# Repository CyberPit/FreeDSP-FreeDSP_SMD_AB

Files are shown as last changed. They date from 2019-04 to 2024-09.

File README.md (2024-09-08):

# FreeDSP-FreeDSP_SMD_AB

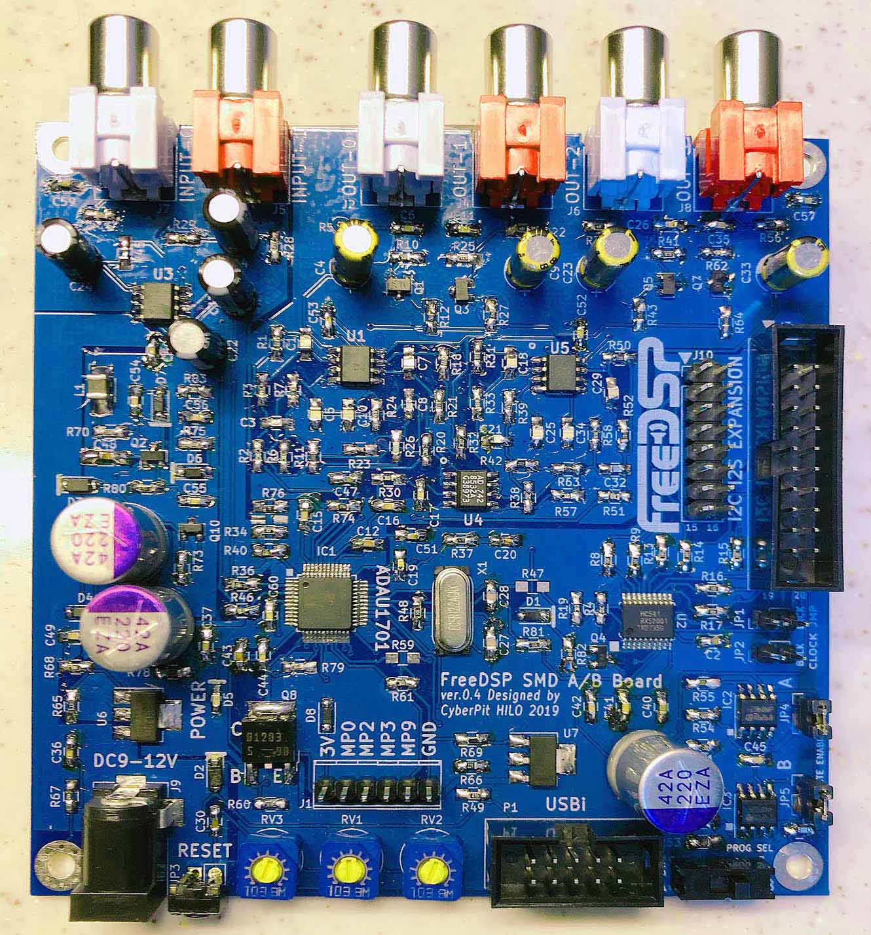
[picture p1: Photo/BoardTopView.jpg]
Image of FreeDSP Classic SMD A/B


- 2in4out RCA jacks
- A/B Selectable Boot EEPROMs
- ADAU1701 Single Board solution
- 0805(2.0mm x 1.25mm) SMD Resistors
- Through-hole Ele-Caps for better Audio performance
- 2V RMS Unity Gain Analog Audio I/O
- Absolute Phase Transparent.
- Power ON/OFF Audio Pops-Muting
- Buffered I2S I/O Headers (with Output Enable control feature)
- Onboard three semi-potentiometers or external controls via header pin. 

Project web page: (Direct Link)
https://cyberpithilo.web.fc2.com/audio/freedsp/index.html

Project web page: (Yandex Machine Translation)
https://translate.yandex.com/translate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

Project web page: (Google Machine Translation)
https://translate.google.com/translate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

I registered this design at SeedStudio(FusionPCB) project Gallary, so you can order this board here easily https://www.seeedstudio.com/FreeDSP-SMD-A-B-ADAU1701-1401-Audio-DSP-Processing-Boar-g-1230721

# License
This work and all other materials under https://github.com/freeDSP are licensed under a Creative Commons Attribution Share-Alike 4.0 license. This allows for both personal and commercial derivative works, as long as they credit freeDSP and release their designs under the same license.

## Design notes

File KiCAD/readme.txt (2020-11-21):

This PCB design was inherit from FreeDSP SMD.
Canages and improved in many points.
- Unity Gain I/O
- Selectable boot EEPROM
- Power ON/OFF Mute
- Buffered I2S I/O Headers

Errata: R49 47k ohms --> 4.7k ohms (Need to pull-up strong)

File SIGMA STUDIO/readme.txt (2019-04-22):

This folder contains example code for my FreeDSP_SMD_AB board.
All design required to output LRCK form MP10 port to drive Charge-Pump Circuity.
You need to set as Serial Output "MASTER MODE" and MP10 "In LRCK_out" in "Hardware Configuration">>"IC1-170x¥140x Register Control" tab.

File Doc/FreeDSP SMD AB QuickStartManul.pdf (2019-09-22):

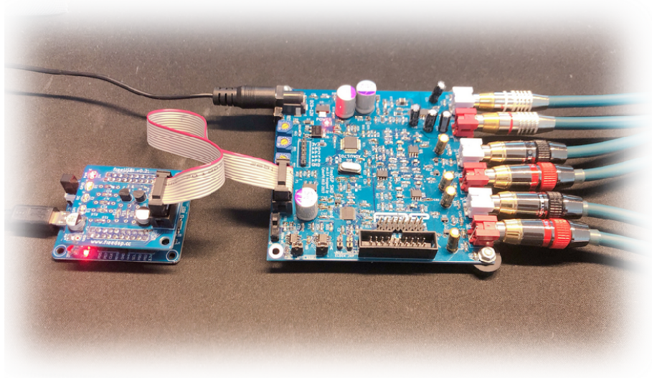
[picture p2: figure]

page of total 3
Quick Start Manual

# FreeDSP Classic SMD A/B

# Quick Start Manual

Version 1.0

## CyberPit HILO

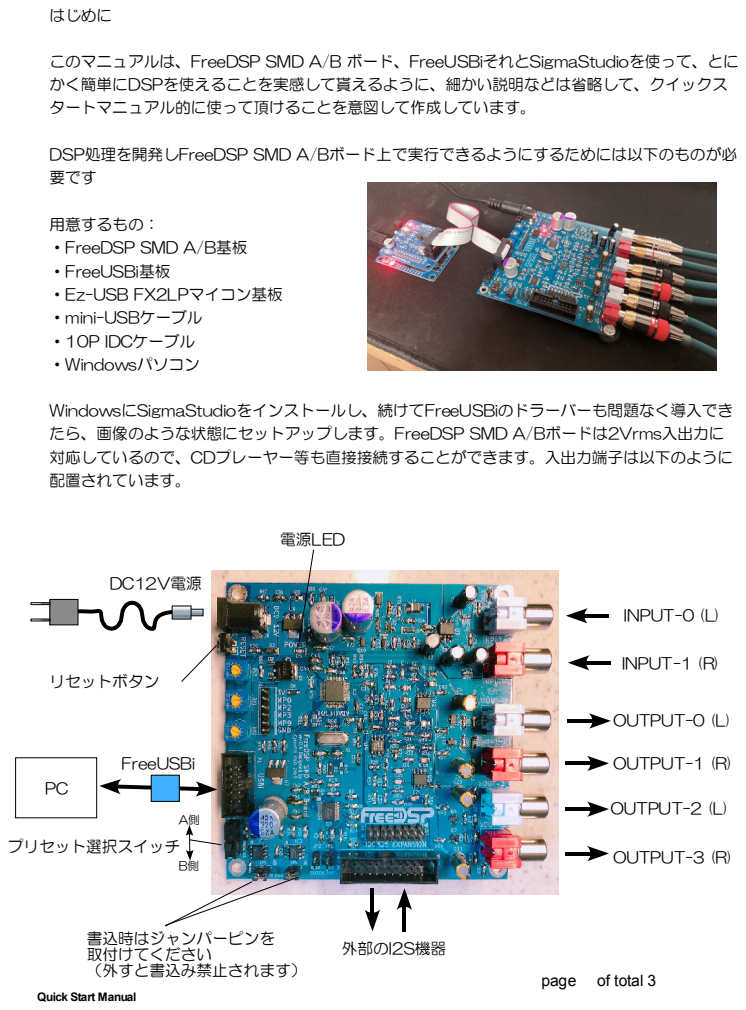
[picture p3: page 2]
はじめに; DC12V電源; INPUT-0 (L); INPUT-1 (R); OUTPUT-0 (L); OUTPUT-1 (R); OUTPUT-2 (L); OUTPUT-3 (R); 外部のI2S機器 書込時はジャンパーピンを 取付けてください （外すと書込み禁止されます）; FreeUSBi; プリセット選択スイッチ; リセットボタン; 電源LED

このマニュアルは、FreeDSP SMD A/B ボード、FreeUSBiそれとSigmaStudioを使って、とに
かく簡単にDSPを使えることを実感して貰えるように、細かい説明などは省略して、クイックス
タートマニュアル的に使って頂けることを意図して作成しています。

DSP処理を開発しFreeDSP SMD A/Bボード上で実行できるようにするためには以下のものが必
要です

用意するもの：
・FreeDSP SMD A/B基板
・FreeUSBi基板
・Ez-USB FX2LPマイコン基板
・mini-USBケーブル
・10P IDCケーブル
・Windowsパソコン

WindowsにSigmaStudioをインストールし、続けてFreeUSBiのドラーバーも問題なく導入でき
たら、画像のような状態にセットアップします。FreeDSP SMD A/Bボードは2Vrms入出力に
対応しているので、CDプレーヤー等も直接接続することができます。入出力端子は以下のように
配置されています。

SigmaStudioの操作：

1. 機材がセットできたらWindowsーPCでSigmaStudioを立ち上げます スタート >> AnalogDevices >> SigmaStudio4.2 >> SigmaStudio4.2
2. SigmaStudioが起動したらプロジェクトファイルを読み込みます
File >> Open 「2wayStereoChanDivDelayVolume .dspproj」を開く
3. 読み込めたら「Hardware Configuration」タブを選んでFreeUSBiが動作している事を確認 しましょう。（USB Interfaceモジュールの一番上の「USB」の文字背景色が緑色）
4. Link >> Compile >> Download ボタンを押してプログラムをDSPに転送します。
5. ２wayのチャンデバとして動作するのでInput0/1にオーディオ信号等を入力して、帯域分割さ れた出力がOut-0/1（低域）、Out-2/3(高域）が出力されるのでアンプとフルレンジSP等を接 続して動作を確認します。今はRV3のポテンショメータが無いので「SW vol」モジュールのゲイ ンが上げられず音がでないので削除しバイパスしてしまいます。
6. 「Schematic」タブを選んでから、「ADCin1」モジュールを削除、「SW vol」モジュールも 削除します。配線が無くなってしまうので緑色の接続点をクリックし接続先までバイパスする配 線を行います。
７. バイパス配線ができたら、Link >> Compile >> Download ボタンを押してプログラムを DSPに転送します。
８. EQモジュールの青いボタンを押してクロス周波数やスロープのパラメーターを変えると音が 変化することを確認してみてください。
9. 左側の「Tree Tool Box」からFileters >> Miscellaneous >> State Variableを選んで配置信 号経路に割り込むように配線してみて下さい。
10. Link >> Compile >> Download ボタンを押してプログラムをDSPに転送します。
11. 周波数やQを可変してみてください
12. 気に入ったセッテイングができたら File >> Save As... で名前を付けてPCに保存します。
13. ボード上のSW1を操作してプログラムを保存する側を選びます
14. 「Hardware Configuration」タブを選んで「ADAU1701」モジュールのIC1を右クリッ クし「Write Latest Compilation to E2ROM」を実行しファームをボードに書き込みます。 15 これで電源を入れればいつでもすぐに使える状態となりました。

サンプルプロジェクトのURL
https://cyberpithilo.web.fc2.com/audio/freedsp/2wayStereoChanDivDelayVolume.zip

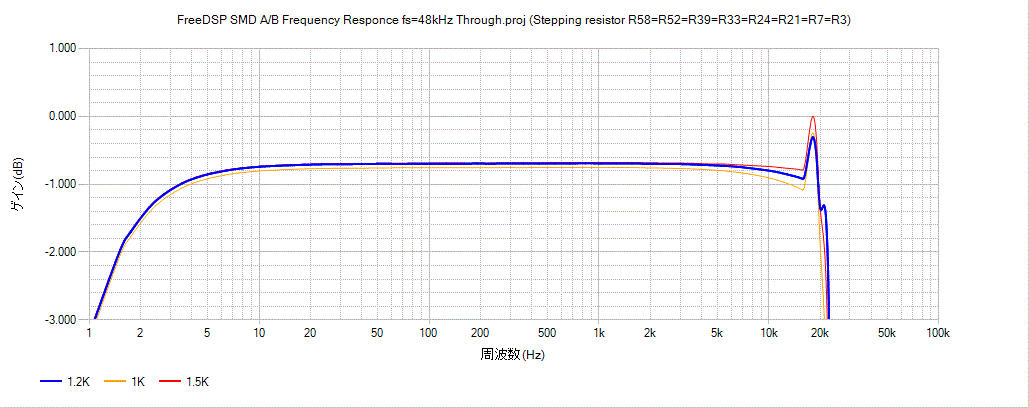
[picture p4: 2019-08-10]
Photo/resp_LPF-R_Stepping48k.gif

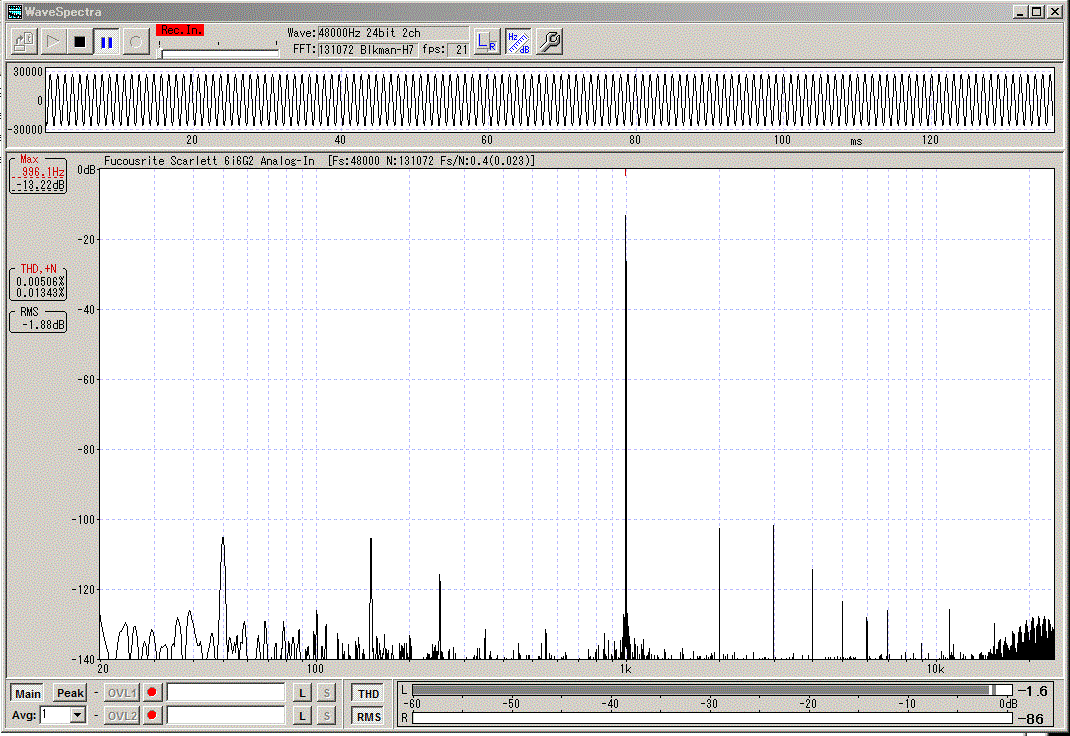
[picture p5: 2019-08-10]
Photo/THD-R.GIF

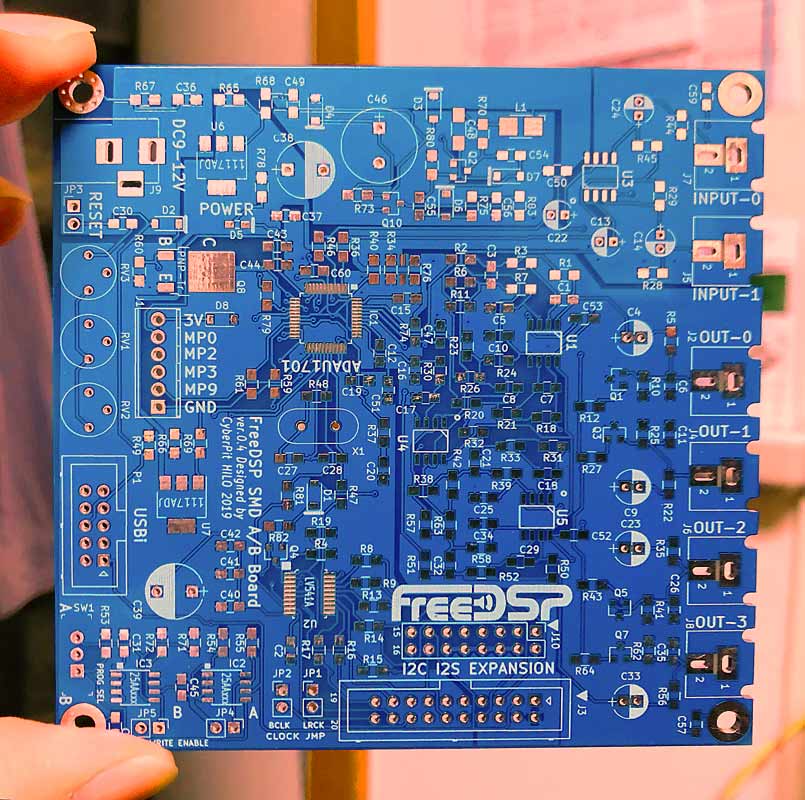
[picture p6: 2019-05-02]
Photo/Rev2BoardArrived.jpg

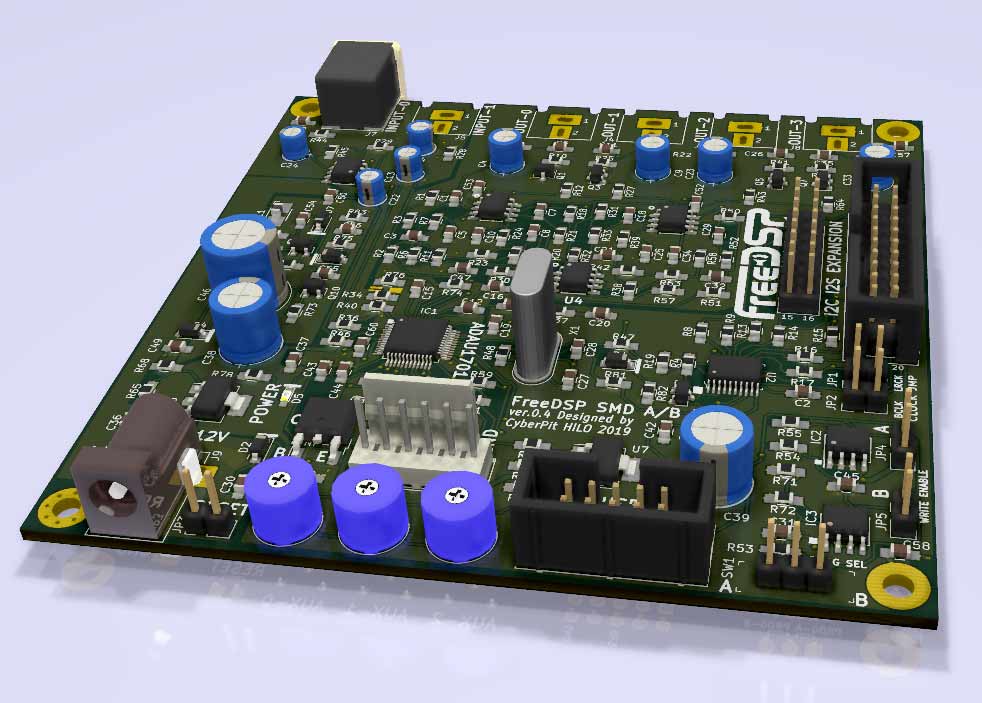
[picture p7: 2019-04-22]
Photo/3Dview_0v4.jpg

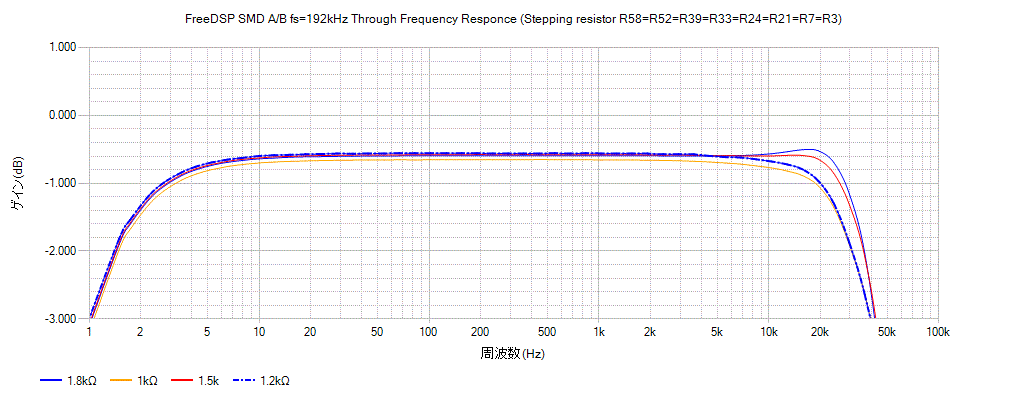
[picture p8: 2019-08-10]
Photo/resp_LPF-R_Stepping192k.GIF

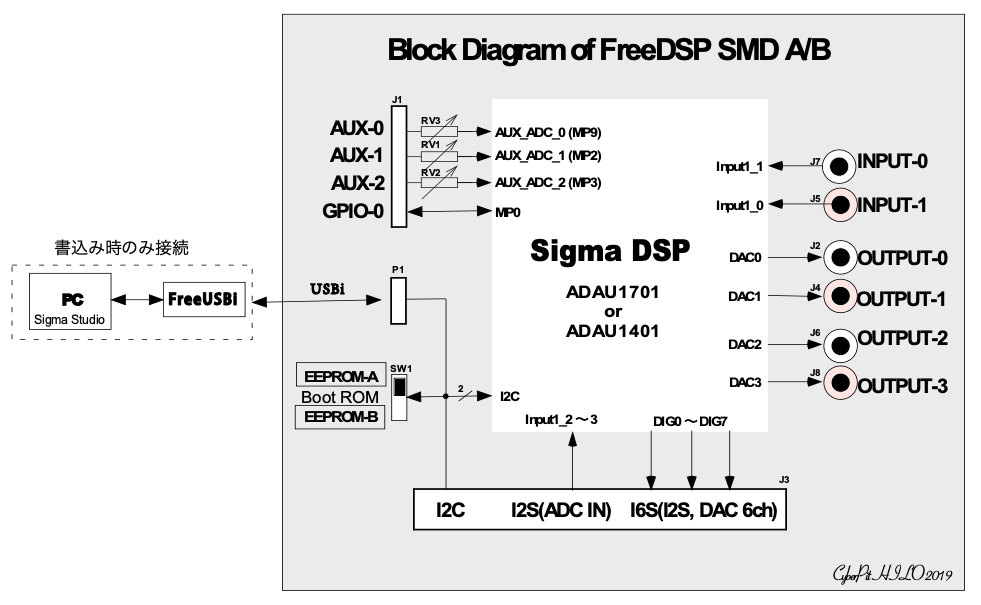
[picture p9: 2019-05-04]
SIGMA STUDIO/BlockDiagram.gif

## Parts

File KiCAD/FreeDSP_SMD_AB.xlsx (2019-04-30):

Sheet: FreeDSP_SMD_AB.csv
Source: |  |  | FreeDSP_SMD_AB.sch
Bill of materials for FreeDSP SDM A/B Board ver 0.4
Date: |  |  | Saturday, 1 Mayl 2019 at 11:13:14
Tool: |  |  | Eeschema (5.1.0-0)
Generator: |  |  | bom_csv_grouped_by_value_with_fp.py |  |  |  |  |  |  | ¥5392
Component Count: |  |  | 194
Ref | Type | OP | Std. Ver. | Optinal Ver. | Footprint | Value | Shop Link1 | Shop Link2 | 参考価格 | 小計
IC1, | U |  | 1 | 1 | QFP:LQFP-48_7x7mm_Pitch0.5mm | Analog Devices DSP ADAU1701 or ADAU1401 | https://jp.rs-online.com/web/p/audio-processors/7592705/ | https://www.digikey.com/product-detail/en/analog-devices-inc/ADAU1701JSTZ/ADAU1701JSTZ-ND/1246074 | ¥1124 | ¥1124
U2, | U | O | 0 | 1 | TSSOP-20_W4.4mm | 8bit 3-state Buffer 74LV541A | http://akizukidenshi.com/catalog/g/gI-03440/ | https://www.digikey.com/product-detail/en/texas-instruments/SN74LV541APWR/296-13700-1-ND/509734 | ¥200 | ¥200
U6, U7, | U |  | 2 | 2 | SOT_Packages_SMD:SOT-223-3_TabPin2 | Variable Voltage Regurator AZ1117-ADJ | http://akizukidenshi.com/catalog/g/gI-11194/ | https://www.digikey.com/product-detail/en/diodes-incorporated/AZ1117EH-ADJTRG1/AZ1117EH-ADJTRG1DICT-ND/5001334 | ¥30 | ¥60
U5, U3, U1, U4, | U |  | 4 | 4 | SOIC127P600X175-8N | Dual Op-Amp LME49720MA or Equiv. | http://akizukidenshi.com/catalog/g/gI-08175/ | https://www.digikey.com/product-detail/en/texas-instruments/LME49720MAX-NOPB/LME49720MAX-NOPBCT-ND/3527060 | ¥180 | ¥720
IC2, IC3, | U |  | 2 | 2 | SOIC-8_3.9x4.9mm_Pitch1.27mm | I2C EEPROM 24AA256 (or Bigger) | http://akizukidenshi.com/catalog/g/gI-10492/ | https://www.digikey.com/product-detail/en/microchip-technology/25AA256-I-SN/25AA256-I-SN-ND/665597 | ¥40 | ¥80
Q1, Q3, Q5, Q7, | Q |  | 4 | 4 | TO_SOT_Packages_SMD:SOT-23 | 2SD2704KT146 or 2SC3326 | http://akizukidenshi.com/catalog/g/gI-06007/ | https://www.digikey.com/product-detail/en/rohm-semiconductor/2SD2704KT146/2SD2704KT146CT-ND/1782342 | ¥5 | ¥20
Q8, | Q |  | 1 | 1 | TO_SOT_Packages_SMD:TO-252-2 | 2SB1203 (PNP transistor, base/collector/emitter) | http://akizukidenshi.com/catalog/g/gI-06602/ | https://www.digikey.com/product-detail/en/on-semiconductor/2SB1203S-TL-E/2SB1203S-TL-EOSCT-ND/5801673 | ¥10 | ¥10
Q2, Q4, | Q |  | 1 | 2 | TO_SOT_Packages_SMD:SOT-23 | 2N7002 (0.115A Id, 60V Vds, N-Channel MOSFET) | http://akizukidenshi.com/catalog/g/gI-04256/ | https://www.digikey.com/product-detail/en/nexperia-usa-inc/2N7002P215/1727-4692-1-ND/2531105 | ¥20 | ¥40
Q10, | Q |  | 1 | 1 | TO_SOT_Packages_SMD:SOT-23 | IRLML6402 (-3.7A Id, -20V Vds, P-Channel MOSFET, 65mOhm Rd) | http://akizukidenshi.com/catalog/g/gI-02553/ | https://www.digikey.com/product-detail/en/infineon-technologies/IRLML6402TRPBF/IRLML6402PBFCT-ND/812500 | ¥20 | ¥20
D3, D2, | D |  | 2 | 2 | Diodes_SMD:D_SOD-123 | Fast Switching Si Diode N4148W | http://akizukidenshi.com/catalog/g/gI-07084/ | https://www.digikey.com/product-detail/en/micro-commercial-co/1N4148WX-TP/1N4148WXTPMSCT-ND/717312 | ¥3 | ¥6
D6, D7, D8, D4, D1, | D |  | 2 | 4 | Diodes_SMD:D_SOD-123 | Schottky diode RB160M-30 | http://akizukidenshi.com/catalog/g/gI-01398/ | https://www.digikey.com/product-detail/en/nexperia-usa-inc/BAT54H115/1727-3569-1-ND/1127204 | ¥15 | ¥60
D5, | D |  | 1 | 1 | LEDs:LED_0603_HandSoldering | SMD LED (1.6mm x 0.8mm, RED) | http://akizukidenshi.com/catalog/g/gI-11879/ | https://www.digikey.com/product-detail/en/rohm-semiconductor/SML-D12U1WT86/SML-D12U1WT86CT-ND/5843858 | ¥10 | ¥10
L1, | L |  | 1 | 1 | Inductors:Inductor_1212 | SMD-INDUCTOR-33uH (700MA,_6mmX6.4mm) | http://akizukidenshi.com/catalog/g/gP-05691/ | https://www.digikey.com/product-detail/en/taiyo-yuden/CB2016T330K/587-2472-1-ND/2230338 | ¥5 | ¥5
R55, R72, R61, R6, R2, R23, R20, R38, R32, R57, R51, R30, R19, R4, R83, | R |  | 14 | 15 | Resistors_SMD:R_0805_HandSoldering | 10k |  |  |  | ¥0
R60, R7, R3, R24, R21, R39, R33, R58, R52, R75, R78, R70, R79, | R |  | 13 | 13 | Resistors_SMD:R_0805_HandSoldering | 1k |  |  |  | ¥0
R1, R18, R31, R50, R11, R26, R42, R63, R64, R43, R27, R12, | R |  | 12 | 12 | Resistors_SMD:R_0805_HandSoldering | 22k |  |  |  | ¥0
R49, R62, R41, R25, R10, R44, R28, | R |  | 7 | 7 | Resistors_SMD:R_0805_HandSoldering | 47k |  |  |  | ¥0
R56, R35, R22, R5, R68, | R |  | 5 | 5 | Resistors_SMD:R_0805_HandSoldering | 680R |  |  |  | ¥0
R45, R29, R67, R74, R82, | R |  | 4 | 5 | Resistors_SMD:R_0805_HandSoldering | 100k |  |  |  | ¥0
R34, R76, R80, | R |  | 3 | 3 | Resistors_SMD:R_0805_HandSoldering | 0R |  |  |  | ¥0
R54, R53, R71, | R |  | 3 | 3 | Resistors_SMD:R_0805_HandSoldering | 2k2 |  |  |  | ¥0
R36, R40, R46, | R |  | 3 | 3 | Resistors_SMD:R_0805_HandSoldering | 18k |  |  |  | ¥0
R66, R65, | R |  | 2 | 2 | Resistors_SMD:R_0805_HandSoldering | 220R |  |  |  | ¥0
R48, R8, R9, R13, R14, R15, R16, R17, R81, | R |  | 1 | 9 | Resistors_SMD:R_0805_HandSoldering | 100R |  |  |  | ¥0
R69, | R |  | 1 | 1 | Resistors_SMD:R_0805_HandSoldering | 360R |  |  |  | ¥0
R37, | R |  | 1 | 1 | Resistors_SMD:R_0805_HandSoldering | 470R |  |  |  | ¥0
R73, | R |  | 1 | 1 | Resistors_SMD:R_0805_HandSoldering | 1MEG |  |  |  | ¥0
C27, C28, | C |  | 2 | 2 | Capacitors_SMD:C_0805_HandSoldering | 22p | MLCC |  | ¥3 | 6
C20, | C |  | 1 | 1 | Capacitors_SMD:C_0805_HandSoldering | 0.056uF | MLCC |  |  | ¥0
C41, | C |  | 1 | 1 | Capacitors_SMD:C_0805_HandSoldering | 1u/6.3V | MLCC |  |  | ¥0
C44, C31, C45, C17, C2, C52, C53, C50, C51, C57, C58, C59, C60, C42, C37, | C |  | 12 | 13 | Capacitors_SMD:C_0805_HandSoldering | 0.1u | MLCC |  |  | 0
C5, C1, C10, C7, C25, C18, C34, C29, | C |  | 8 | 8 | Film Capacitors_SMD:C_0805_HandSoldering | 150P (Panasonic ECHU) | https://www.sengoku.co.jp/mod/sgk_cart/search.php?cid=3300 | https://www.digikey.com/product-detail/en/panasonic-electronic-components/ECH-U1C151JX5/PCF1461CT-ND/431695 | ¥34 | 272
C3, C8, C21, C32, | C |  | 4 | 4 | Film Capacitors_SMD:C_0805_HandSoldering | 1000PF (Panasonic ECHU) | https://www.sengoku.co.jp/mod/sgk_cart/search.php?cid=3300 | https://www.digikey.com/product-detail/en/panasonic-electronic-components/ECH-U1C102JX5/PCF1471CT-ND/431715 | ¥34 | 136
C19, C35, C26, C11, C6, | C |  | 5 | 5 | Capacitors_SMD:C_0805_HandSoldering | 3300pF | MLCC |  |  | 0
C43, C16, C12, C15, C40, | C |  | 7 | 7 | Capacitors_SMD:C_0805_HandSoldering | 10u/6.3V | MLCC |  |  | 0
C36, C48, | C |  | 7 | 7 | Capacitors_SMD:C_0805_HandSoldering | 10u/16V | MLCC |  |  | 0
C30, C47, C49 | C |  | 6 | 6 | Capacitors_SMD:C_0805_HandSoldering | 2.2u/6.3V | MLCC |  |  | 0
C54, C55, C56, | C |  | 6 | 6 | Capacitors_SMD:C_0805_HandSoldering | 2.2u/16V | MLCC |  |  | 0
C24, C14, | C |  | 2 | 2 | Capacitors_THT:CP_Radial_D4.0mm_P2.00mm | Polarized capacitor 2.2uF/16 | http://akizukidenshi.com/catalog/g/gP-03171/ |  | ¥10 | 20
C4, C9, C23, C33, | C |  | 4 | 4 | Capacitors_THT:CP_Radial_D5.0mm_P2.00mm | Polarized capacitor10u/16V | http://akizukidenshi.com/catalog/g/gP-04621/ |  | ¥10 | 40
C13, C22, | C |  | 2 | 2 | Capacitors_THT:CP_Radial_D4.0mm_P2.00mm | Polarized capacitor 47uF/6.3 | http://akizukidenshi.com/catalog/g/gP-05186/ |  | ¥20 | 40
C46, | C |  | 1 | 1 | Capacitors_THT:CP_Radial_Tantal_D10.5mm_P5.00mm | Polarized capacitor 220u/6.3V | http://akizukidenshi.com/catalog/g/gP-10272/ |  | ¥20 | 20
C38, C39, | C |  | 2 | 2 | Capacitors_THT:CP_Radial_D8.0mm_P5.00mm | Polarized capacitor 220u/16V | http://akizukidenshi.com/catalog/g/gP-10272/ |  | ¥20 | 40
SW1, | S |  | 1 | 1 | Switch_Slide_11.6x4mm_EG1218 | Slide SW_SPDT | http://akizukidenshi.com/catalog/g/gP-08790/ | https://www.digikey.com/product-detail/en/te-connectivity-alcoswitch-switches/1825282-1/450-1635-ND/1308844 | ¥20 | ¥20
X1, | X |  | 1 | 1 | Crystals:Crystal_HC49-U_Vertical | 12.288MHz Crystal | https://jp.rs-online.com/web/p/crystal-units/5476496/ | https://www.digikey.com/product-detail/en/txc-corporation/9B-12.288MEEJ-B/887-1239-ND/2207659 | ¥143 | ¥143
JP4, JP5, JP2, JP1, | H |  | 2 | 4 | Pin_Headers:Pin_Header_Straight_1x02_Pitch2.54mm | 2P Pin Header Conn_01x02 (P=2.54mm) | http://akizukidenshi.com/catalog/g/gC-08593/ | https://www.digikey.com/product-detail/en/harwin-inc/M20-9990246/952-2262-ND/3728226 | ¥3 | ¥12
JP3, | H |  | 1 | 1 | Pin_Headers:Pin_Header_Straight_1x02_Pitch2.54mm | SPST TACT Push Switch or 2P Pin Header | http://akizukidenshi.com/catalog/g/gP-08080/ | https://www.digikey.com/product-detail/en/omron-electronics-inc-emc-div/B3WN-6002/SW425CT-ND/277858 | ¥12 | ¥12
P1, | H |  | 1 | 1 | Connectors_Multicomp:Multicomp_MC9A12-1034_2x05x2.54mm_Straight | 10P MIL Male MIL Header Conn_02x05 (P=2.54mm) for USBi | http://akizukidenshi.com/catalog/g/gC-12664/ | https://www.digikey.com/product-detail/en/on-shore-technology-inc/302-S101/ED1543-ND/2178422 | ¥20 | ¥20
J5, J2, J6, | J |  | 6 | 6 | MyFootprints:RJ-2410N | Single RCA Conn_Coaxial (WHITE) | http://akizukidenshi.com/catalog/g/gC-02386/ | https://www.digikey.com/product-detail/en/switchcraft-inc/PJRAN1X1U02X/PJRAN1X1U02X-ND/1832412 | ¥40 | ¥240
J7, J4, J8, | J |  | 6 | 6 | MyFootprints:RJ-2410N | Single RCA Conn_Coaxial (RED) | http://akizukidenshi.com/catalog/g/gC-02385/ | https://www.digikey.com/product-detail/en/cui-inc/RCJ-042/CP-1419-ND/408506 | ¥40 | ¥240
J9, | J |  | 1 | 1 | Connect:BARREL_JACK | DC Power Jack (2.1mm Center, 5.5mm Sleeve) | http://akizukidenshi.com/catalog/g/gC-06568/ | https://www.digikey.com/product-detail/en/adafruit-industries-llc/3643/1528-2553-ND/8346574 | ¥40 | ¥40
RV3, RV2, RV1, | V | O | 0 | 3 | Potentiometers:Potentiometer_Trimmer_Bourns_3339P_Horizontal | POT_TRIM RESISTOR B10K | http://akizukidenshi.com/catalog/g/gP-06110/ | https://www.digikey.com/product-detail/en/bourns-inc/3339H-1-103LF/3339H-103LF-ND/1088280 | ¥50 | ¥150
J1, | H | O | 0 | 1 | TerminalBlock_Phoenix:TerminalBlock_Phoenix_MPT-2.54mm_6pol | 6P Pin Header 01x06 (P=2.54mm) | http://akizukidenshi.com/catalog/g/gC-01669/ | https://www.digikey.com/product-detail/en/te-connectivity-amp-connectors/640456-6/A1923-ND/109008 | ¥20 | ¥20
J10, | H | O | 0 | 1 | Pin_Headers:Pin_Header_Straight_2x08_Pitch2.54mm | 16P Pin Header Conn_02x08 (P=2.54mm) | http://akizukidenshi.com/catalog/g/gC-00082/ | https://www.digikey.com/product-detail/en/amphenol-icc-fci/68602-116HLF/609-3364-ND/1878523 | ¥50 | ¥50
J3, | H | O | 0 | 1 | Connectors_Multicomp:Multicomp_MC9A12-2034_2x10x2.54mm_Straight | 20P Pin Header 02x10 (P=2.54) | http://akizukidenshi.com/catalog/g/gC-05176/ | https://www.digikey.com/product-detail/en/on-shore-technology-inc/302-S201/ED10524-ND/2794235 | ¥20 | ¥20
 |  |  |  |  |  |  |  |  |  | ¥908
AC ADOUPTOR (DC12V 1A, 2.1mm Center +) | P |  | 1 | 1 | Power Supply (DC12V, 1A, 2.1mm Center Positive, 5.5mm Sleeve) |  | http://akizukidenshi.com/catalog/g/gM-11994/ |  | ¥580 | ¥580
Jumper Short-Pin (for Write Enables) | J |  | 2 | 2 | Jumper Short-Pin |  | http://akizukidenshi.com/catalog/g/gP-03687/ | https://www.digikey.com/product-detail/en/3m/D89110-0131HK-3365-10-D-6/3M156030-MC10G-3M156030-6-ND/6024552 | ¥4 | 8

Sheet: FreeUSBi_ThroughHole.csv
Reference | Qty. | Value | SMD/TH | Footprint | Shop URL
P1, P4 | 2 | CONN_02X10 | COM | Pin_Header_Socker Straight_2x10 | http://akizukidenshi.com/catalog/g/gC-00083/
P2 | 1 | CONN_02X05 | COM | IDC-Header_2x05_Pitch2.54mm_Straight | http://akizukidenshi.com/catalog/g/gC-12664/
D1 | 1 | LED | COM | LEDs:LED-3MM
D2 | 1 | LED | COM | LEDs:LED-3MM
D3 | 1 | LED | COM | LEDs:LED-3MM
D4 | 1 | LED | COM | LEDs:LED-3MM
C1、C2 | 2 | 100u | COM | Capacitors_Elko_ThroughHole:Elko_vert_11.2x6.3mm_RM2.5_CopperClear
P3 | 1 | CONN_01X02 | NOPOP | fdsp_pinheader:Pin_Header_Straight_1x02 | Directly Jumper wire conncetion to the Ez-USB FX2LP Board 5V
Q1, Q2 | 2 | 2N7000 | TH | TO_SOT_Packages_THT:TO-92_Inline_Narrow_Oval | http://akizukidenshi.com/catalog/g/gI-13045/
R1 | 1 | 51R | TH | Resistors_THT:R_Axial_DIN0204_L3.6mm_D1.6mm_P7.62mm_Horizontal | Free Size (1.6mm x 0.8mm, 2.0mm x 1.25mm, 3.2mm x 1.6mm)
R2, R5, R6, R7, R9 | 5 | 470R | TH | Resistors_THT:R_Axial_DIN0204_L3.6mm_D1.6mm_P7.62mm_Horizontal | Free Size (1.6mm x 0.8mm, 2.0mm x 1.25mm, 3.2mm x 1.6mm)
R8 | 1 | 1M | TH | Resistors_THT:R_Axial_DIN0204_L3.6mm_D1.6mm_P7.62mm_Horizontal | Free Size (1.6mm x 0.8mm, 2.0mm x 1.25mm, 3.2mm x 1.6mm)
R3, R4 | 2 | 10k | TH | Resistors_THT:R_Axial_DIN0204_L3.6mm_D1.6mm_P7.62mm_Horizontal | Free Size (1.6mm x 0.8mm, 2.0mm x 1.25mm, 3.2mm x 1.6mm)
10P IDC Cable Assy. | 1 | - | COM | Programming Cable | http://akizukidenshi.com/catalog/g/gC-03796/
Mini USB Cable | 1 | - | COM | USB-A to mini-USB | http://akizukidenshi.com/catalog/g/gC-07606/
Ez-USB FX2LP Board | 1 | - | COM | Various Choice | https://www.amazon.co.jp/SODIAL-%E9%96%8B%E7%99%BA%E3%83%9C%E3%83%BC%E3%83%89USB2-0-EZ-USB-FX2LP-CY7C68013A/dp/B00OCEEIX0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

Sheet: FreeUSBi_SMD.csv
Reference | Qty. | Value | SMD/TH | Footprint | Shop URL
P1, P4 | 2 | CONN_02X10 | COM | Pin_Header_Socker Straight_2x10 | http://akizukidenshi.com/catalog/g/gC-00083/
P2 | 1 | CONN_02X05 | COM | IDC-Header_2x05_Pitch2.54mm_Straight | http://akizukidenshi.com/catalog/g/gC-12664/
D1 | 1 | LED | COM | LEDs:LED-3MM
D2 | 1 | LED | COM | LEDs:LED-3MM
D3 | 1 | LED | COM | LEDs:LED-3MM
D4 | 1 | LED | COM | LEDs:LED-3MM
C1、C2 | 2 | 100u | COM | Capacitors_Elko_ThroughHole:Elko_vert_11.2x6.3mm_RM2.5_CopperClear | http://akizukidenshi.com/catalog/g/gP-05002/
P3 | 1 | CONN_01X02 | NOPOP | fdsp_pinheader:Pin_Header_Straight_1x02 | Directly Jumper wire conncetion to the Ez-USB FX2LP Board 5V
Q3, Q4 | 2 | 2N7002 | SMD | digikey-footprints:SOT-23-3 | http://akizukidenshi.com/catalog/g/gI-04256/
R10 | 1 | 51R | SMD | Resistors_SMD:R_0805_HandSoldering
R11, R13, R16, R17, R18 | 5 | 470R | SMD | Resistors_SMD:R_0805_HandSoldering
R14 | 1 | 1M | SMD | Resistors_SMD:R_0805_HandSoldering
R12, R15 | 2 | 10k | SMD | Resistors_SMD:R_0805_HandSoldering
10P IDC Cable Assy. | 1 | - | COM | Programming Cable | http://akizukidenshi.com/catalog/g/gC-03796/
Mini USB Cable | 1 | - | COM | USB-A to mini-USB | http://akizukidenshi.com/catalog/g/gC-07606/
Ez-USB FX2LP Board | 1 | - | COM | Various Choice | https://www.amazon.co.jp/SODIAL-%E9%96%8B%E7%99%BA%E3%83%9C%E3%83%BC%E3%83%89USB2-0-EZ-USB-FX2LP-CY7C68013A/dp/B00OCEEIX0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

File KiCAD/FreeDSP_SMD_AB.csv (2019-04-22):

Source: | FreeDSP_SMD_AB.sch
Date: | Saturday, 20 April 2019 at 11:13:14
Tool: | Eeschema (5.1.0-0)
Generator: | bom_csv_grouped_by_value_with_fp.py
Component Count: | 194
Ref | Std. Ver. | Optinal Ver. | Footprint | Value | Shop Link1 | Shop Link2 | 参考価格 | 小計
IC1, | 1 | 1 | Housings_QFP:LQFP-48_7x7mm_Pitch0.5mm | Analog Devices DSP ADAU1701 | https://jp.rs-online.com/web/p/audio-processors/7089748/ |  | 1243 | 1243
U5, U3, U1, U4, | 4 | 4 | LME49720MA_NOPB:SOIC127P600X175-8N | Dual Op-Amp LME49720MA or Equiv. | http://akizukidenshi.com/catalog/g/gI-08175/ |  | 180 | 720
U2, | 0 | 1 | digikey-footprints:TSSOP-20_W4.4mm | 8bit 3-state Buffer 74LV541A | http://akizukidenshi.com/catalog/g/gI-03440/ |  | 200 | 200
IC2, IC3, | 2 | 2 | Housings_SOIC:SOIC-8_3.9x4.9mm_Pitch1.27mm | I2C EEPROM 24AA256 (or Bigger) | http://akizukidenshi.com/catalog/g/gI-10492/ |  | 40 | 80
Q8, | 1 | 1 | TO_SOT_Packages_SMD:TO-252-2 | 2SB1203 (PNP transistor, base/collector/emitter) | http://akizukidenshi.com/catalog/g/gI-06602/ |  | 10 | 10
Q1, Q3, Q5, Q7, | 4 | 4 | TO_SOT_Packages_SMD:SOT-23 | 2SD2704KT146 or 2SC3326 | http://akizukidenshi.com/catalog/g/gI-06007/ |  | 5 | 20
Q2, Q4, | 1 | 2 | TO_SOT_Packages_SMD:SOT-23 | 2N7002 (0.115A Id, 60V Vds, N-Channel MOSFET) | http://akizukidenshi.com/catalog/g/gI-04256/ |  | 20 | 40
Q10, | 1 | 1 | TO_SOT_Packages_SMD:SOT-23 | IRLML6402 (-3.7A Id, -20V Vds, P-Channel MOSFET, 65mOhm Rd) | http://akizukidenshi.com/catalog/g/gI-02553/ |  | 20 | 20
U6, U7, | 2 | 2 | TO_SOT_Packages_SMD:SOT-223-3_TabPin2 | Variable Voltage Regurator AZ1117-ADJ | http://akizukidenshi.com/catalog/g/gI-11194/ |  | 30 | 60
D5, | 1 | 1 | LEDs:LED_0603_HandSoldering | SMD LED (1.6mm x 0.8mm, RED) | http://akizukidenshi.com/catalog/g/gI-11879/ |  | 10 | 10
D3, D2, | 2 | 2 | Diodes_SMD:D_SOD-123 | Fast Switching Si Diode N4148W | http://akizukidenshi.com/catalog/g/gI-07084/ |  | 3 | 6
D6, D7, D8, D4, D1, | 2 | 4 | Diodes_SMD:D_SOD-123 | Schottky diode RB160M-30 | http://akizukidenshi.com/catalog/g/gI-01398/ |  | 15 | 60
X1, | 1 | 1 | Crystals:Crystal_HC49-U_Vertical | 12.288MHz Crystal | https://jp.rs-online.com/web/p/crystal-units/5476496/ |  | 143 | 143
RV3, RV2, RV1, | 0 | 3 | Potentiometers:Potentiometer_Trimmer_Bourns_3339P_Horizontal | POT_TRIM RESISTOR B10K | http://akizukidenshi.com/catalog/g/gP-06110/ |  | 50 | 150
JP3, | 1 | 1 | Pin_Headers:Pin_Header_Straight_1x02_Pitch2.54mm | SPST TACT Push Switch or 2P Pin Header | http://akizukidenshi.com/catalog/g/gP-08080/ |  | 12 | 12
JP4, JP5, JP2, JP1, | 2 | 4 | Pin_Headers:Pin_Header_Straight_1x02_Pitch2.54mm | 2P Pin Header Conn_01x02 (P=2.54mm) | http://akizukidenshi.com/catalog/g/gC-08593/ |  | 3 | 12
J1, | 0 | 1 | TerminalBlock_Phoenix:TerminalBlock_Phoenix_MPT-2.54mm_6pol | 6P Pin Header 01x06 (P=2.54mm) | http://akizukidenshi.com/catalog/g/gC-01669/ |  | 20 | 20
J10, | 0 | 1 | Pin_Headers:Pin_Header_Straight_2x08_Pitch2.54mm | 16P Pin Header Conn_02x08 (P=2.54mm) | http://akizukidenshi.com/catalog/g/gC-00082/ |  | 50 | 50
J3, | 0 | 1 | Connectors_Multicomp:Multicomp_MC9A12-2034_2x10x2.54mm_Straight | 20P Pin Header 02x10 (P=2.54) | http://akizukidenshi.com/catalog/g/gC-05176/ |  | 20 | 20
P1, | 1 | 1 | Connectors_Multicomp:Multicomp_MC9A12-1034_2x05x2.54mm_Straight | 10P MIL Male MIL Header Conn_02x05 (P=2.54mm) for USBi | http://akizukidenshi.com/catalog/g/gC-12664/ |  | 20 | 20
J5, J2, J6, | 6 | 6 | MyFootprints:RJ-2410N | Single RCA Conn_Coaxial (WHITE) | http://akizukidenshi.com/catalog/g/gC-02386/ |  | 40 | 240
J7, J4, J8, | 6 | 6 | MyFootprints:RJ-2410N | Single RCA Conn_Coaxial (RED) | http://akizukidenshi.com/catalog/g/gC-02385/ |  | 40 | 240
J9, | 1 | 1 | Connect:BARREL_JACK | DC Power Jack (2.1mm Center, 5.5mm Sleeve) | http://akizukidenshi.com/catalog/g/gC-06568/ |  | 40 | 40
SW1, | 1 | 1 | digikey-footprints:Switch_Slide_11.6x4mm_EG1218 | Slide SW_SPDT | http://akizukidenshi.com/catalog/g/gP-08790/ |  | 20 | 20
L1, | 1 | 1 | Inductors:Inductor_1212 | SMD-INDUCTOR-10uH (225MA,_0806) | http://akizukidenshi.com/catalog/g/gP-06984/ |  | 5 | 5
C46, | 1 | 1 | Capacitors_THT:CP_Radial_Tantal_D10.5mm_P5.00mm | Polarized capacitor 220u/6.3V | http://akizukidenshi.com/catalog/g/gP-10272/ |  | 20 | 20
C38, C39, | 2 | 2 | Capacitors_THT:CP_Radial_D8.0mm_P5.00mm | Polarized capacitor 220u/16V | http://akizukidenshi.com/catalog/g/gP-10272/ |  | 20 | 40
C4, C9, C23, C33, | 4 | 4 | Capacitors_THT:CP_Radial_D5.0mm_P2.00mm | Polarized capacitor10u/16V | http://akizukidenshi.com/catalog/g/gP-04621/ |  | 10 | 40
C13, C22, | 2 | 2 | Capacitors_THT:CP_Radial_D4.0mm_P2.00mm | Polarized capacitor 47uF/6.3 | http://akizukidenshi.com/catalog/g/gP-05186/ |  | 20 | 40
C24, C14, | 2 | 2 | Capacitors_THT:CP_Radial_D4.0mm_P2.00mm | Polarized capacitor 2.2uF/16 | http://akizukidenshi.com/catalog/g/gP-03171/ |  | 10 | 20
C27, C28, | 2 | 2 | Capacitors_SMD:C_0805_HandSoldering | 22p |  |  | 3 | 6
C5, C1, C10, C7, C25, C18, C34, C29, | 8 | 8 | Film Capacitors_SMD:C_0805_HandSoldering | 150P (Panasonic ECHU) | https://www.sengoku.co.jp/mod/sgk_cart/search.php?cid=3300 |  | 34 | 272
C3, C8, C21, C32, | 4 | 4 | Film Capacitors_SMD:C_0805_HandSoldering | 1000PF (Panasonic ECHU) | https://www.sengoku.co.jp/mod/sgk_cart/search.php?cid=3300 |  | 34 | 136
C19, C35, C26, C11, C6, | 5 | 5 | Capacitors_SMD:C_0805_HandSoldering | 3300pF |  |  |  | 0
C20, | 1 | 1 | Capacitors_SMD:C_0805_HandSoldering | 0.056uF |  |  |  | 0
C44, C31, C45, C17, C2, C52, C53, C50, C51, C57, C58, C59, C60, C42, C37, | 12 | 13 | Capacitors_SMD:C_0805_HandSoldering | 0.1u |  |  |  | 0
C41, | 1 | 1 | Capacitors_SMD:C_0805_HandSoldering | 1u/6.3V |  |  |  | 0
C30, C47, C49 | 6 | 6 | Capacitors_SMD:C_0805_HandSoldering | 2.2u/6.3V |  |  |  | 0
C54, C55, C56, | 6 | 6 | Capacitors_SMD:C_0805_HandSoldering | 2.2u/16V |  |  |  | 0
C43, C16, C12, C15, C40, | 7 | 7 | Capacitors_SMD:C_0805_HandSoldering | 10u/6.3V |  |  |  | 0
C36, C48, | 7 | 7 | Capacitors_SMD:C_0805_HandSoldering | 10u/16V |  |  |  | 0
R34, R76, R80, | 3 | 3 | Resistors_SMD:R_0805_HandSoldering | 0R |  |  |  | 0
R48, R8, R9, R13, R14, R15, R16, R17, R81, | 1 | 9 | Resistors_SMD:R_0805_HandSoldering | 100R |  |  |  | 0
R66, R65, | 2 | 2 | Resistors_SMD:R_0805_HandSoldering | 220R |  |  |  | 0
R69, | 1 | 1 | Resistors_SMD:R_0805_HandSoldering | 360R |  |  |  | 0
R37, | 1 | 1 | Resistors_SMD:R_0805_HandSoldering | 470R |  |  |  | 0
R56, R35, R22, R5, R68, | 5 | 5 | Resistors_SMD:R_0805_HandSoldering | 680R |  |  |  | 0
R60, R7, R3, R24, R21, R39, R33, R58, R52, R75, R78, R70, R79, | 13 | 13 | Resistors_SMD:R_0805_HandSoldering | 1k |  |  |  | 0
R54, R53, R71, | 3 | 3 | Resistors_SMD:R_0805_HandSoldering | 2k2 |  |  |  | 0
R55, R72, R61, R6, R2, R23, R20, R38, R32, R57, R51, R30, R19, R4, R83, | 14 | 15 | Resistors_SMD:R_0805_HandSoldering | 10k |  |  |  | 0
R36, R40, R46, | 3 | 3 | Resistors_SMD:R_0805_HandSoldering | 18k |  |  |  | 0
R1, R18, R31, R50, R11, R26, R42, R63, R64, R43, R27, R12, | 12 | 12 | Resistors_SMD:R_0805_HandSoldering | 22k |  |  |  | 0
R49, R62, R41, R25, R10, R44, R28, | 7 | 7 | Resistors_SMD:R_0805_HandSoldering | 47k
R45, R29, R67, R74, R82, | 4 | 5 | Resistors_SMD:R_0805_HandSoldering | 100k
R73, | 1 | 1 | Resistors_SMD:R_0805_HandSoldering | 1MEG
 |  |  |  |  |  |  |  | 4015

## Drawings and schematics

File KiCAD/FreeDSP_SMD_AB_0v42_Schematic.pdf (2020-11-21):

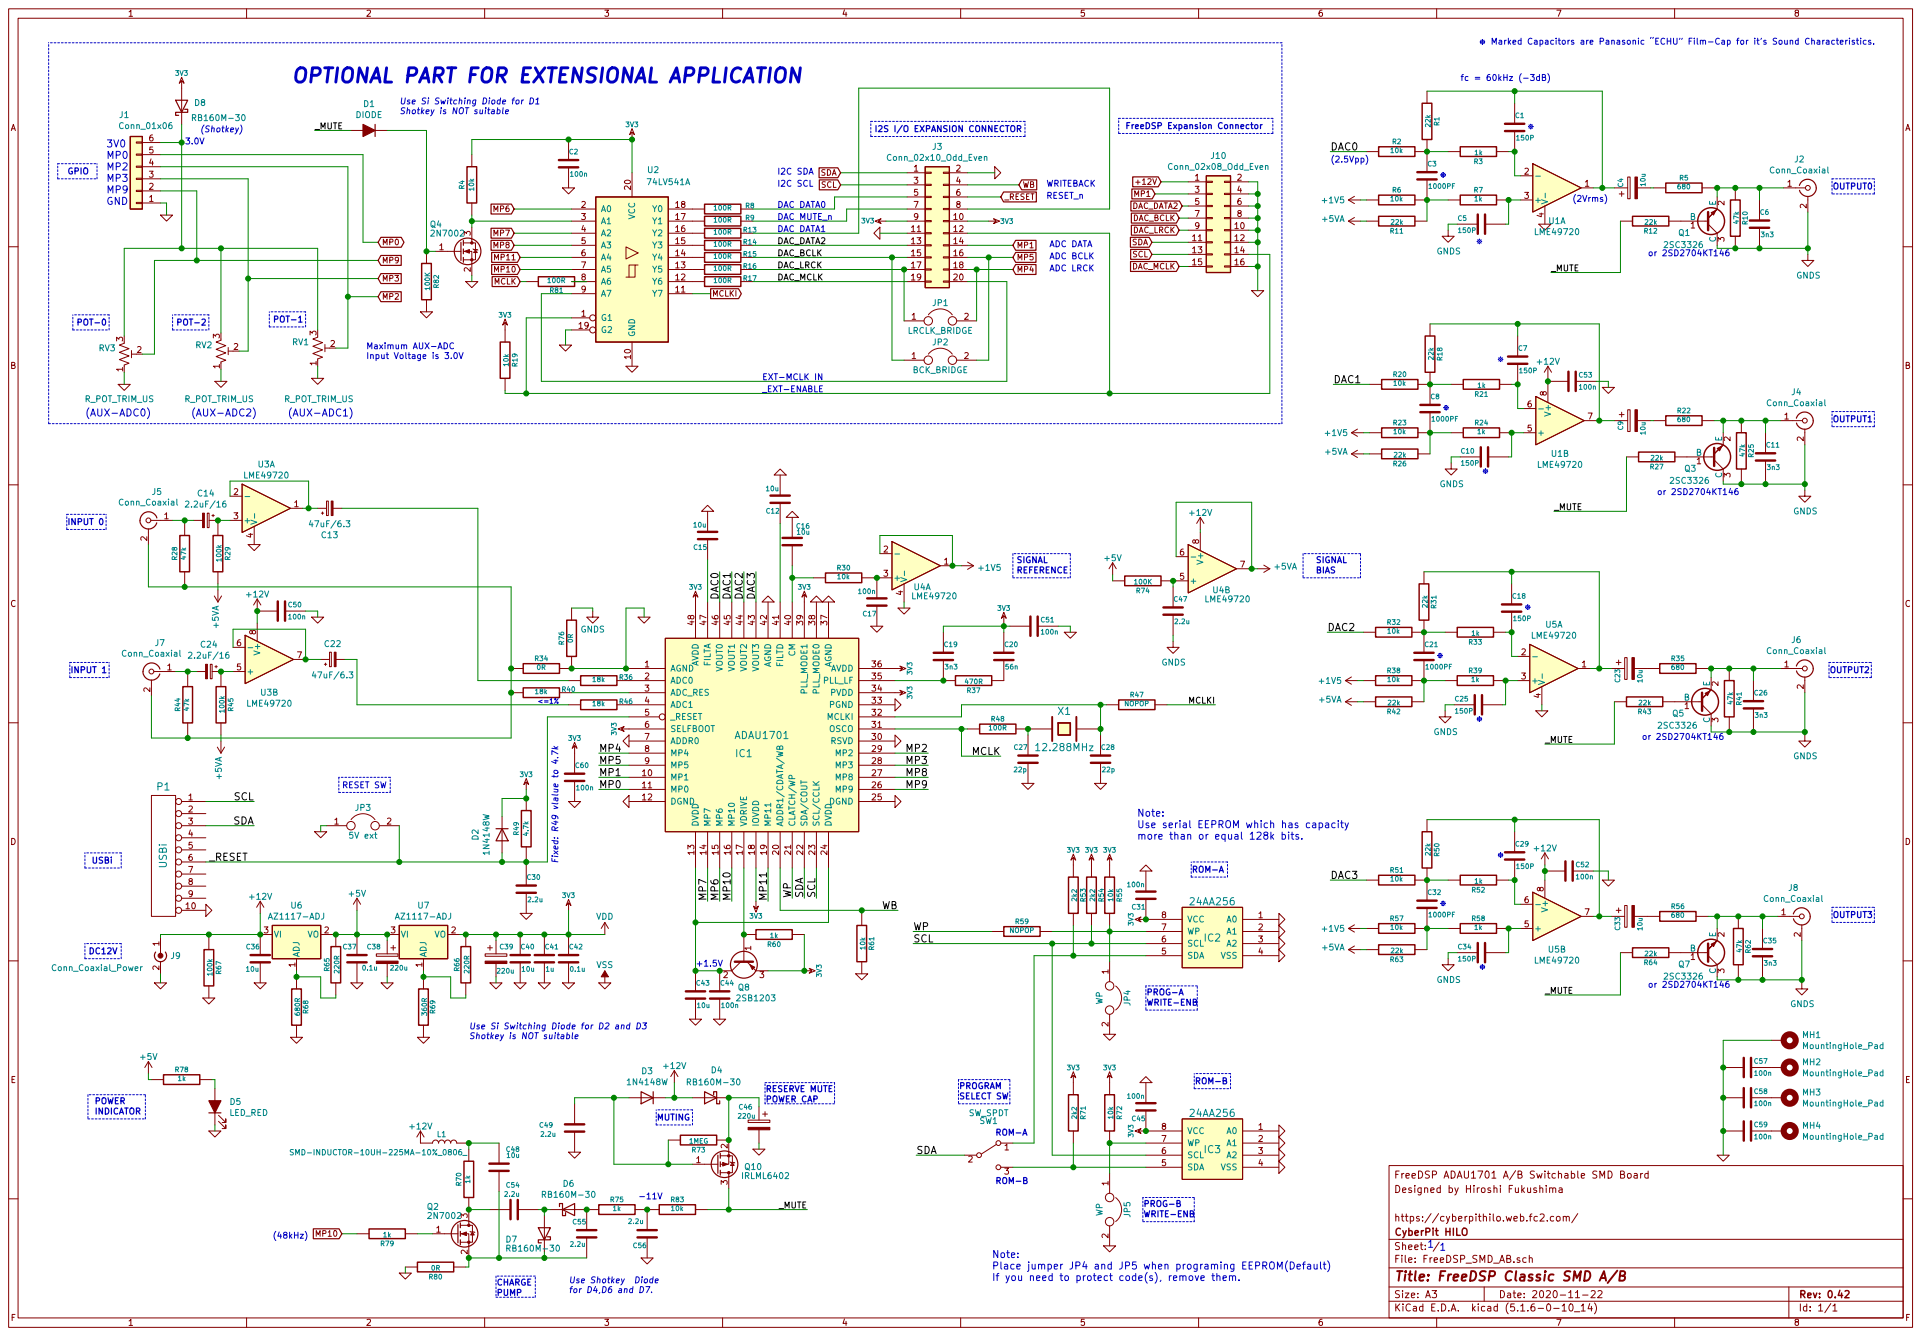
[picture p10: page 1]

Marked Capacitors are Panasonic ECHU Film-Cap for its Sound Characteristics.

I2C SDA OPTIONAL PART FOR EXTENSIONAL APPLICATION

fc = 60kHz (-3dB) Note: Use serial EEPROM which has capacity

Use Si Switching Diode for D1
Shotkey is NOT suitable

1 2 WP JP4 GNDS GNDS GNDS

more than or equal 128k bits. ROM-A

POWER CAP Use Si Switching Diode for D2 and D3

Designed by Hiroshi Fukushima FreeDSP ADAU1701 A/B Switchable SMD Board

https://cyberpithilo.web.fc2.com/
File: FreeDSP_SMD_AB.sch Sheet: / CyberPit HILO
Id: 1/1 Title: FreeDSP Classic SMD A/B

Note: Place jumper JP4 and JP5 when programing EEPROM(Default)

If you need to protect code(s), remove them.

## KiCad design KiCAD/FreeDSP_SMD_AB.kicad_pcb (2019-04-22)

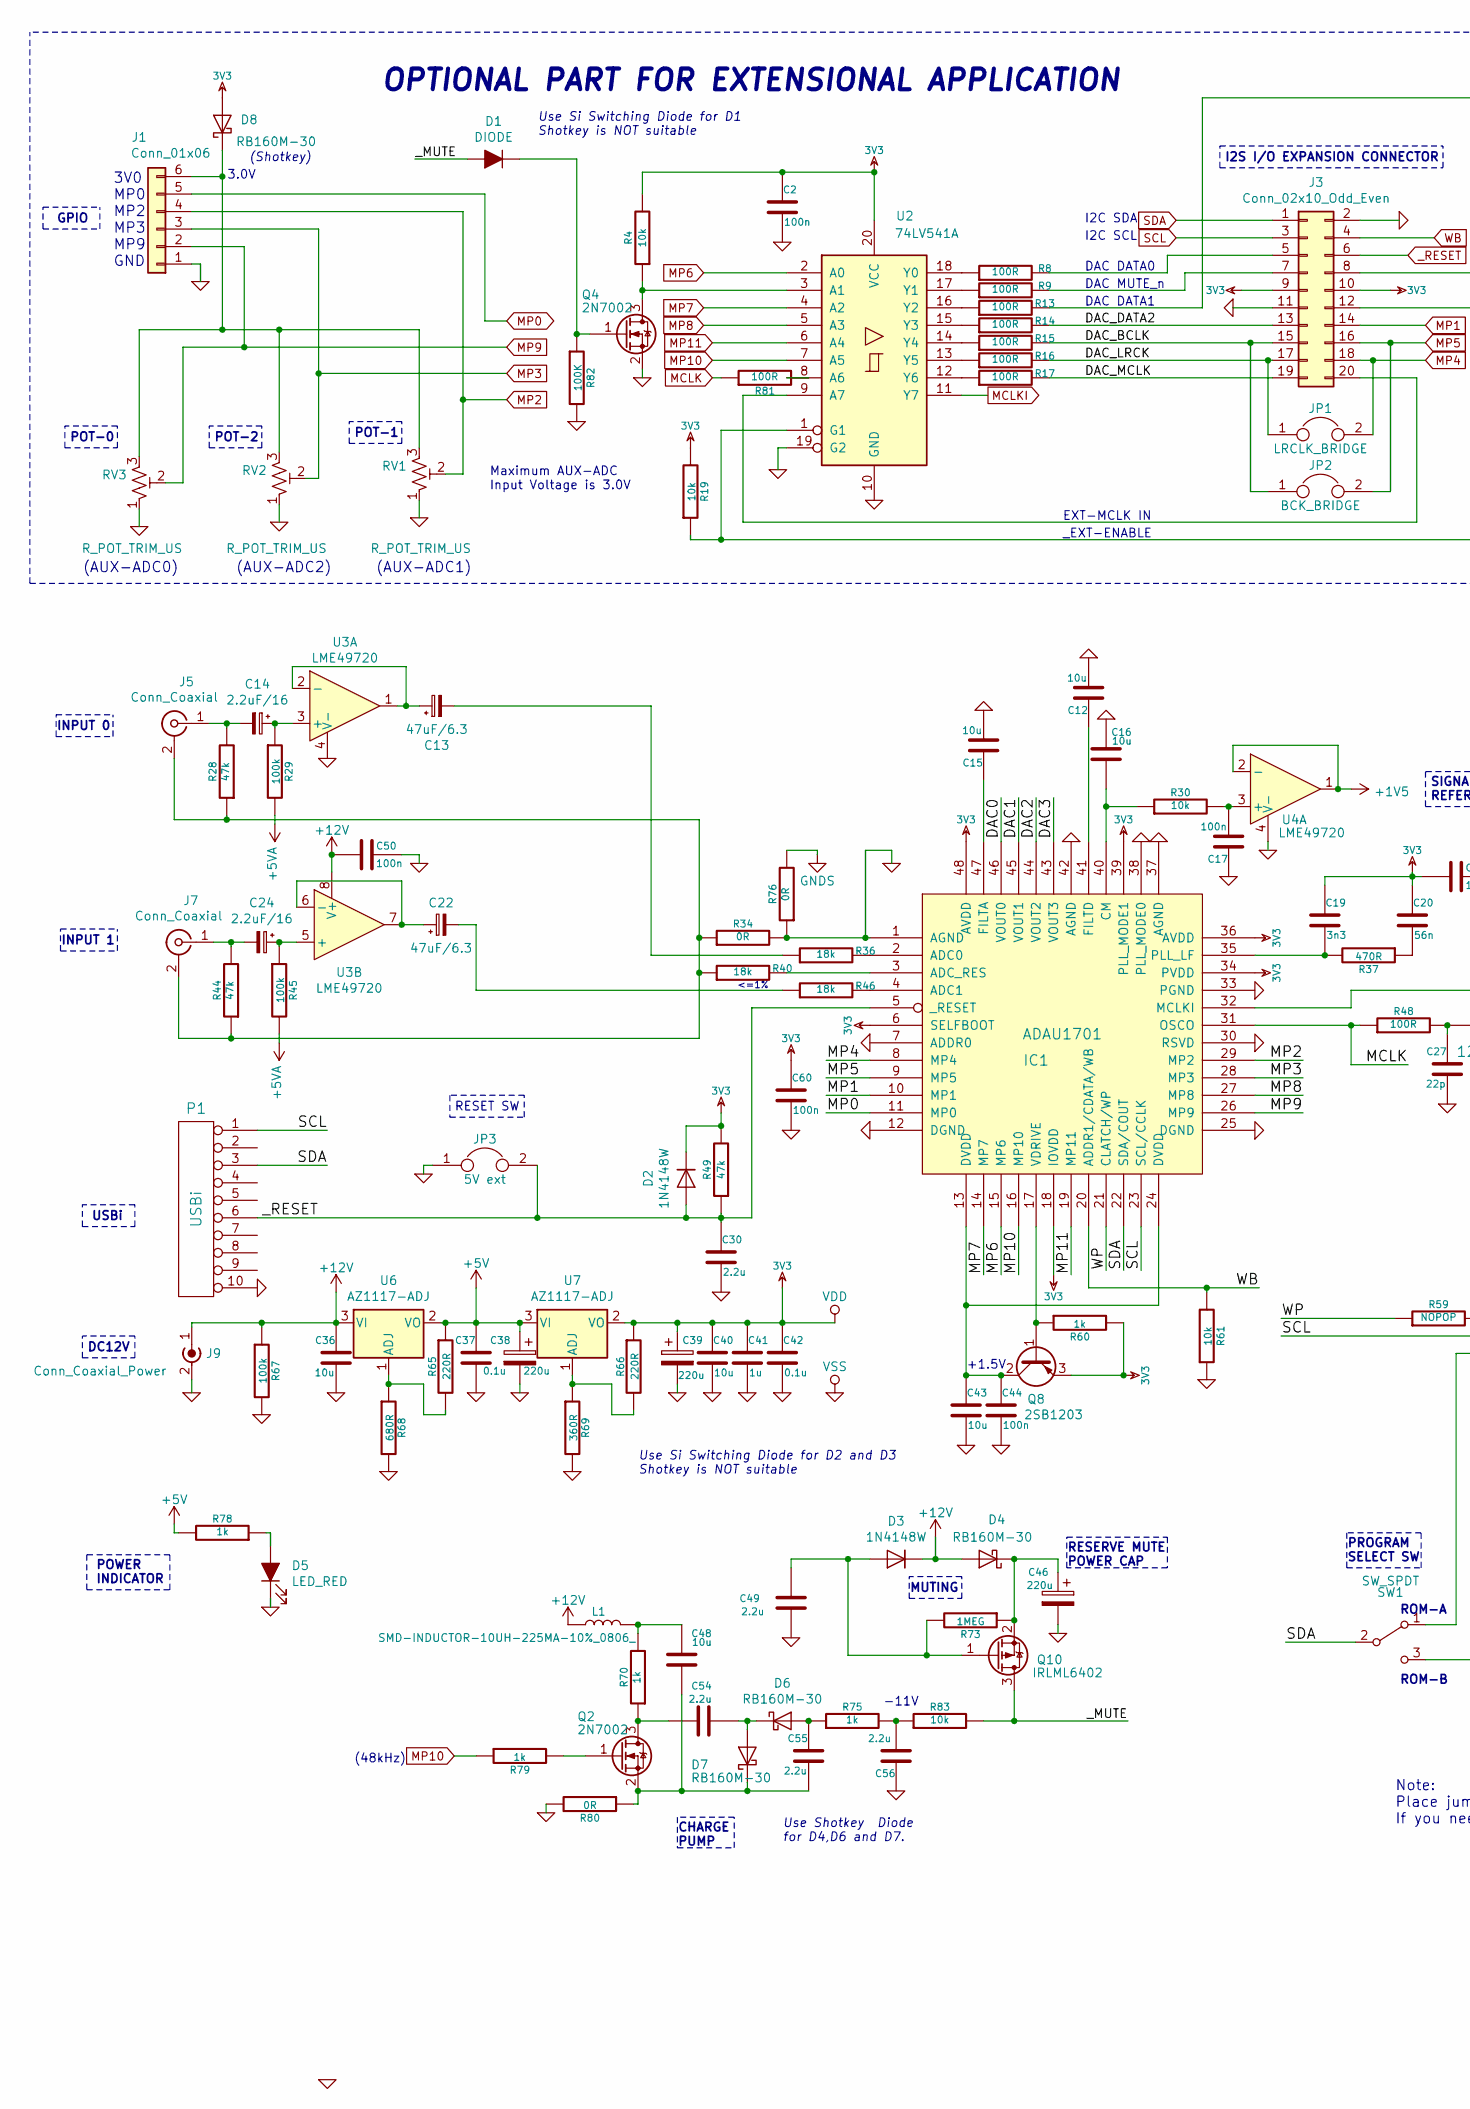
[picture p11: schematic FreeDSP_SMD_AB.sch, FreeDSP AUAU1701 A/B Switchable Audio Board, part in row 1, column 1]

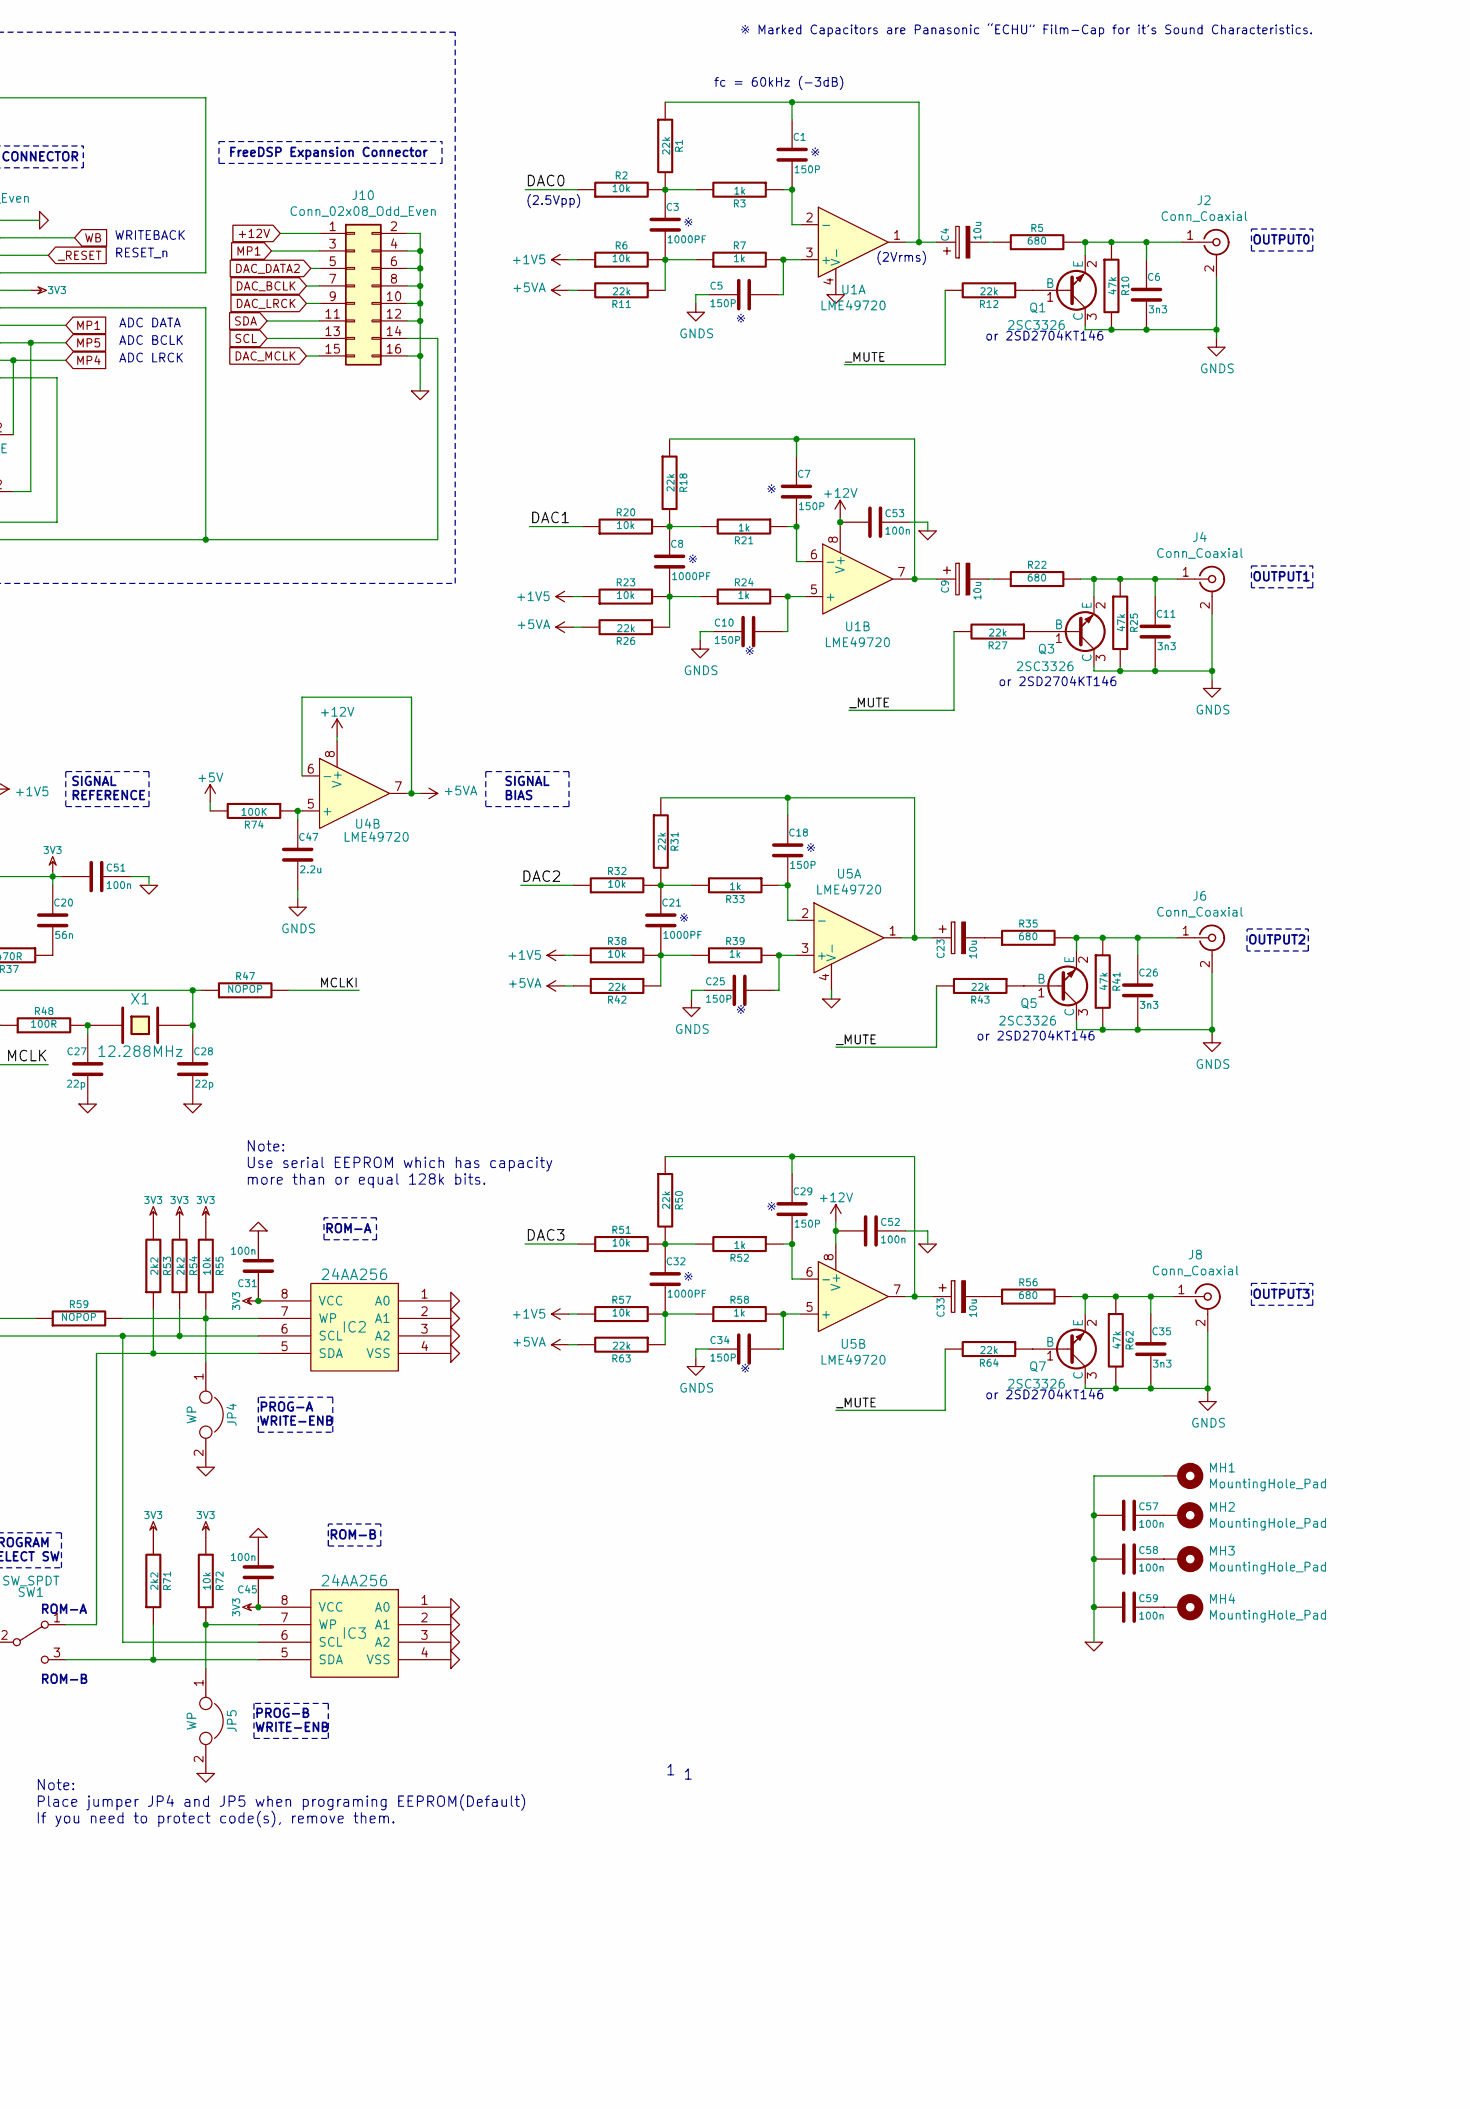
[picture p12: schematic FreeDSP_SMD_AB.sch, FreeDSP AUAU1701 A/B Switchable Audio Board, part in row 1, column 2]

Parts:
C1, C5, C7, C10, C18, C25, C29, C34: 150P; C_0805_HandSoldering
C2, C17, C31, C44, C45, C50, C51, C52, C53, C57, C58, C59, C60: 100n; C_0805_HandSoldering
C3, C8, C21, C32: 1000PF; C_0805_HandSoldering
C4, C9, C23, C33: 10u; CP_Radial_D5.0mm_P2.00mm
C6, C11, C19, C26, C35: 3n3; C_0805_HandSoldering
C12, C15, C16, C36, C40, C43: 10u; C_0805_HandSoldering
C13, C22: 47uF/6.3; CP_Radial_D4.0mm_P2.00mm
C14, C24: 2.2uF/16; CP_Radial_D4.0mm_P2.00mm
C20: 56n; C_0805_HandSoldering
C27, C28: 22p; C_0805_HandSoldering
C30, C47, C49, C54, C55, C56: 2.2u; C_0805_HandSoldering
C37, C42: 0.1u; C_0805_HandSoldering
C38, C39: 220u; CP_Radial_D8.0mm_P5.00mm
C41: 1u; C_0805_HandSoldering
C46: 220u; CP_Radial_Tantal_D10.5mm_P5.00mm
C48: 10u; C_1206_HandSoldering
D1: DIODE; D_SOD-123
D2, D3: 1N4148W; D_SOD-123
D4, D6, D7, D8: RB160M-30; D_SOD-123
D5: LED_RED; LED_0603_HandSoldering
IC1: ADAU1701; LQFP-48_7x7mm_Pitch0.5mm
IC2, IC3: 24AA256; SOIC-8_3.9x4.9mm_Pitch1.27mm
J1: Conn_01x06; TerminalBlock_Phoenix_MPT-2.54mm_6pol
J2, J4, J5, J6, J7, J8: Conn_Coaxial; RJ-2410N
J3: Conn_02x10_Odd_Even; Multicomp_MC9A12-2034_2x10x2.54mm_Straight
J9: Conn_Coaxial_Power; BARREL_JACK
J10: Conn_02x08_Odd_Even; Pin_Header_Straight_2x08_Pitch2.54mm
JP1: LRCLK_BRIDGE; Pin_Header_Straight_1x02_Pitch2.54mm
JP2: BCK_BRIDGE; Pin_Header_Straight_1x02_Pitch2.54mm
JP3: 5V ext; Pin_Header_Straight_1x02_Pitch2.54mm
JP4, JP5: WP; Pin_Header_Straight_1x02_Pitch2.54mm
L1: SMD-INDUCTOR-10UH-225MA-10%_0806_; Inductor_1212; MPN LQH2MCN100K02L
MH1: MountingHole_Pad; MountingHole_3.2mm_M3_Pad_Via
MH2, MH3, MH4: MountingHole_Pad; MountingHole_3.2mm_M3_Pad
P1: USBi; Multicomp_MC9A12-1034_2x05x2.54mm_Straight
Q1, Q3, Q5, Q7: 2SC3326; SOT-23
Q2, Q4: 2N7002; SOT-23
Q8: 2SB1203; TO-252-2
Q10: IRLML6402; SOT-23
R1, R11, R12, R18, R26, R27, R31, R42, R43, R50, R63, R64: 22k; R_0805_HandSoldering
R2, R4, R6, R19, R20, R23, R30, R32, R38, R51, R55, R57, R61, R72, R83: 10k; R_0805_HandSoldering
R3, R7, R21, R24, R33, R39, R52, R58, R60, R70, R75, R78, R79: 1k; R_0805_HandSoldering
R5, R22, R35, R56: 680; R_0805_HandSoldering
R8, R9, R13, R14, R15, R16, R17, R48, R81: 100R; R_0805_HandSoldering
R10, R25, R28, R41, R44, R49, R62: 47k; R_0805_HandSoldering
R29, R45, R67: 100k; R_0805_HandSoldering
R34, R76, R80: 0R; R_0805_HandSoldering
R36, R40, R46: 18k; R_0805_HandSoldering
R37: 470R; R_0805_HandSoldering
R47, R59: NOPOP; R_0805_HandSoldering
R53, R54, R71: 2k2; R_0805_HandSoldering
R65, R66: 220R; R_0805_HandSoldering
R68: 680R; R_0805_HandSoldering
R69: 360R; R_0805_HandSoldering
R73: 1MEG; R_0805_HandSoldering
R74, R82: 100K; R_0805_HandSoldering
RV1, RV2, RV3: R_POT_TRIM_US; Potentiometer_Trimmer_Bourns_3339P_Horizontal
SW1: SW_SPDT; Switch_Slide_11.6x4mm_EG1218
U1, U3, U4, U5: LME49720; SOIC127P600X175-8N
U2: 74LV541A; TSSOP-20_W4.4mm
U6, U7: AZ1117-ADJ; SOT-223-3_TabPin2
X1: 12.288MHz; Crystal_HC49-U_Vertical

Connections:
3V3: C2.1, C19.1, C20.1, C31.1, C39.1, C40.1, C41.1, C42.1, C45.1, C51.2, C60.1, D2.1 (K), D8.2 (A), IC1.6 (SELFBOOT), IC1.18 (IOVDD), IC1.34 (PVDD), IC1.36 (AVDD), IC1.39 (PLL_MODE1), IC1.48 (AVDD), IC2.8 (VCC), IC3.8 (VCC), J3.9, J3.10, Q8.3 (E), R4.2, R19.2, R49.2, R53.2, R54.2, R55.2, R60.2, R66.1, R71.2, R72.2, U2.20 (VCC), U7.2 (VO)
+1V5: R6.1, R23.1, R38.1, R57.1, U4.1, U4.2 (-)
+5V: C37.1, C38.1, R65.1, R74.2, R78.2, U6.2 (VO), U7.3 (VI)
+5VA: R11.2, R26.2, R29.2, R42.2, R45.2, R63.2, U4.6 (-), U4.7
+12V: C36.1, C50.2, C52.2, C53.2, D3.1 (K), D4.2 (A), J9.1 (In), J10.1, L1.1, R67.1, U1.8 (V+), U3.8 (V+), U4.8 (V+), U5.8 (V+), U6.3 (VI)
/DAC0: IC1.46 (VOUT0), R2.1
/DAC1: IC1.45 (VOUT1), R20.1
/DAC2: IC1.44 (VOUT2), R32.1
/DAC3: IC1.43 (VOUT3), R51.1
/WP: IC1.21 (CLATCH/WP), R59.1
/_MUTE: D1.2 (A), Q10.3 (D), R12.2, R27.2, R43.2, R64.2, R83.2
DAC_BCLK: J3.15, J10.7, JP2.1, R15.2
DAC_DATA2: J3.13, J10.5, R14.2
DAC_LRCK: J3.17, J10.9, JP1.1, R16.2
DAC_MCLK: J3.19, J10.15, R17.2
GND: C2.2, C12.2, C15.2, C16.2, C17.1, C27.2, C28.2, C30.2, C31.2, C36.2, C37.2, C38.2, C39.2, C40.2, C41.2, C42.2, C43.2, C44.2, C45.2, C46.2, C49.2, C50.1, C51.1, C52.1, C53.1, C56.1, C57.2, C58.2, C59.2, C60.2, D5.1 (K), IC1.1 (AGND), IC1.7 (ADDR0), IC1.12 (DGND), IC1.25 (DGND), IC1.30 (RSVD), IC1.33 (PGND), IC1.37 (AGND), IC1.38 (PLL_MODE0), IC1.42 (AGND), IC2.1 (A0), IC2.2 (A1), IC2.3 (A2), IC2.4 (VSS), IC3.1 (A0), IC3.2 (A1), IC3.3 (A2), IC3.4 (VSS), J1.1, J3.2, J3.11, J9.2 (Ext), J10.2, J10.4, J10.6, J10.8, J10.10, J10.12, J10.16, JP3.1, JP4.2, JP5.2, MH1.1, P1.10, Q4.2 (S), R34.2, R61.1, R67.2, R68.2, R69.2, R76.1, R80.2, R82.2, RV1.1, RV2.1, RV3.1, U1.4 (V-), U2.10 (GND), U2.19 (G2), U3.4 (V-), U4.4 (V-), U5.4 (V-)
GNDS: C5.2, C6.2, C10.2, C11.2, C25.2, C26.2, C34.2, C35.2, C47.2, J2.2 (Ext), J4.2 (Ext), J6.2 (Ext), J8.2 (Ext), Q1.3 (C), Q3.3 (C), Q5.3 (C), Q7.3 (C), R10.2, R25.2, R41.2, R62.2, R76.2
MCLK: IC1.31 (OSCO), R48.1, R81.1
MCLKI: R47.2, U2.11 (Y7)
MP0: IC1.11 (MP0), J1.5
MP1: IC1.10 (MP1), J3.14, J10.3
MP2: IC1.29 (MP2), J1.4, RV1.2
MP3: IC1.28 (MP3), J1.3, RV2.2
MP4: IC1.8 (MP4), J3.18, JP1.2
MP5: IC1.9 (MP5), J3.16, JP2.2
MP6: IC1.15 (MP6), U2.2 (A0)
MP7: IC1.14 (MP7), U2.4 (A2)
MP8: IC1.27 (MP8), U2.5 (A3)
MP9: IC1.26 (MP9), J1.2, RV3.2
MP10: IC1.16 (MP10), R79.1, U2.7 (A5)
MP11: IC1.19 (MP11), U2.6 (A4)
unnamed: C1.1, C4.1, R1.1, U1.1
unnamed: C1.2, R3.1, U1.2 (-)
unnamed: C3.1, R1.2, R2.2, R3.2
unnamed: C3.2, R6.2, R7.1, R11.1
unnamed: C4.2, R5.1
unnamed: C5.1, R7.2, U1.3 (+)
unnamed: C6.1, J2.1 (In), Q1.2 (E), R5.2, R10.1
unnamed: C7.1, C9.1, R18.1, U1.7
unnamed: C7.2, R21.1, U1.6 (-)
unnamed: C8.1, R18.2, R20.2, R21.2
unnamed: C8.2, R23.2, R24.1, R26.1
unnamed: C9.2, R22.1
unnamed: C10.1, R24.2, U1.5 (+)
unnamed: C11.1, J4.1 (In), Q3.2 (E), R22.2, R25.1
unnamed: C12.1, IC1.41 (FILTD)
unnamed: C13.1, U3.1, U3.2 (-)
unnamed: C13.2, R36.1
unnamed: C14.1, R29.1, U3.3 (+)
unnamed: C14.2, J5.1 (In), R28.2
unnamed: C15.1, IC1.47 (FILTA)
unnamed: C16.1, IC1.40 (CM), R30.1
unnamed: C17.2, R30.2, U4.3 (+)
unnamed: C18.1, C23.1, R31.1, U5.1
unnamed: C18.2, R33.1, U5.2 (-)
unnamed: C19.2, IC1.35 (PLL_LF), R37.2
unnamed: C20.2, R37.1
unnamed: C21.1, R31.2, R32.2, R33.2
unnamed: C21.2, R38.2, R39.1, R42.1
unnamed: C22.1, U3.6 (-), U3.7
unnamed: C22.2, R46.1
unnamed: C23.2, R35.1
unnamed: C24.1, R45.1, U3.5 (+)
unnamed: C24.2, J7.1 (In), R44.2
unnamed: C25.1, R39.2, U5.3 (+)
unnamed: C26.1, J6.1 (In), Q5.2 (E), R35.2, R41.1
unnamed: C27.1, R48.2, X1.1
unnamed: C28.1, IC1.32 (MCLKI), R47.1, X1.2
unnamed: C29.1, C33.1, R50.1, U5.7
unnamed: C29.2, R52.1, U5.6 (-)
unnamed: C32.1, R50.2, R51.2, R52.2
unnamed: C32.2, R57.2, R58.1, R63.1
unnamed: C33.2, R56.1
unnamed: C34.1, R58.2, U5.5 (+)
unnamed: C35.1, J8.1 (In), Q7.2 (E), R56.2, R62.1
unnamed: C43.1, C44.1, IC1.13 (DVDD), IC1.24 (DVDD), Q8.2 (C)
unnamed: C46.1, D4.1 (K), Q10.2 (S), R73.1
unnamed: C47.1, R74.1, U4.5 (+)
unnamed: C48.1, L1.2, R70.2
unnamed: C48.2, C55.2, D7.1 (K), Q2.2 (S), R80.1
unnamed: C49.1, D3.2 (A), Q10.1 (G), R73.2
unnamed: C54.1, Q2.3 (D), R70.1
unnamed: C54.2, D6.1 (K), D7.2 (A)
unnamed: C55.1, D6.2 (A), R75.1
unnamed: C56.2, R75.2, R83.1
unnamed: C57.1, MH2.1
unnamed: C58.1, MH3.1
unnamed: C59.1, MH4.1
unnamed: D1.1 (K), Q4.1 (G), R82.1
unnamed: D5.2 (A), R78.1
unnamed: D8.1 (K), J1.6, RV1.3, RV2.3, RV3.3
unnamed: IC1.2 (ADC0), R36.2
unnamed: IC1.3 (ADC_RES), R40.2
unnamed: IC1.4 (ADC1), R46.2
unnamed: IC1.17 (VDRIVE), Q8.1 (B), R60.1
unnamed: IC2.5 (SDA), R53.1, SW1.1 (A)
unnamed: IC2.7 (WP), JP4.1, R55.1, R59.2
unnamed: IC3.5 (SDA), R71.1, SW1.3 (C)
unnamed: IC3.7 (WP), JP5.1, R72.1
unnamed: J3.5, R8.2
unnamed: J3.7, R9.2
unnamed: J3.8, R13.2
unnamed: J3.20, U2.9 (A7)
unnamed: J5.2 (Ext), J7.2 (Ext), R28.1, R34.1, R40.1, R44.1
unnamed: J3.12, J10.14, R19.1, U2.1 (G1)
unnamed: Q1.1 (B), R12.1
unnamed: Q2.1 (G), R79.2
unnamed: Q3.1 (B), R27.1
unnamed: Q4.3 (D), R4.1, U2.3 (A1)
unnamed: Q5.1 (B), R43.1
unnamed: Q7.1 (B), R64.1
unnamed: R8.1, U2.18 (Y0)
unnamed: R9.1, U2.17 (Y1)
unnamed: R13.1, U2.16 (Y2)
unnamed: R14.1, U2.15 (Y3)
unnamed: R15.1, U2.14 (Y4)
unnamed: R16.1, U2.13 (Y5)
unnamed: R17.1, U2.12 (Y6)
unnamed: R65.2, R68.1, U6.1 (ADJ)
unnamed: R66.2, R69.1, U7.1 (ADJ)
unnamed: R81.2, U2.8 (A6)
SCL: IC1.23 (SCL/CCLK), IC2.6 (SCL), IC3.6 (SCL), J3.3, J10.13, P1.1, R54.1
SDA: IC1.22 (SDA/COUT), J3.1, J10.11, P1.3, SW1.2 (B)
WB: IC1.20 (ADDR1/CDATA/WB), J3.4, R61.2
_RESET: C30.1, D2.2 (A), IC1.5 (_RESET), J3.6, JP3.2, P1.6, R49.1

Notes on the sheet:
<=1%
RESET SW
DAC DATA0
DAC MUTE_n
I2C SCL
I2C SDA
RESET_n
DAC DATA1
EXT-MCLK IN
ADC LRCK
ADC BCLK
ADC DATA
I2S I/O EXPANSION CONNECTOR
WRITEBACK
POT-0
POT-1
POT-2
ROM-A
ROM-B
USBi
DC12V
fc = 60kHz (-3dB)
(2.5Vpp)
(2Vrms)
MUTING
INPUT 0
INPUT 1
OUTPUT0
OUTPUT1
OUTPUT2
OUTPUT3
PROGRAM SELECT SW
SIGNAL REFERENCE
SIGNAL BIAS
_EXT-ENABLE
PROG-A WRITE-ENB
PROG-B WRITE-ENB
GPIO
3V0 MP0 MP2 MP3 MP9 GND
OPTIONAL PART FOR EXTENSIONAL APPLICATION

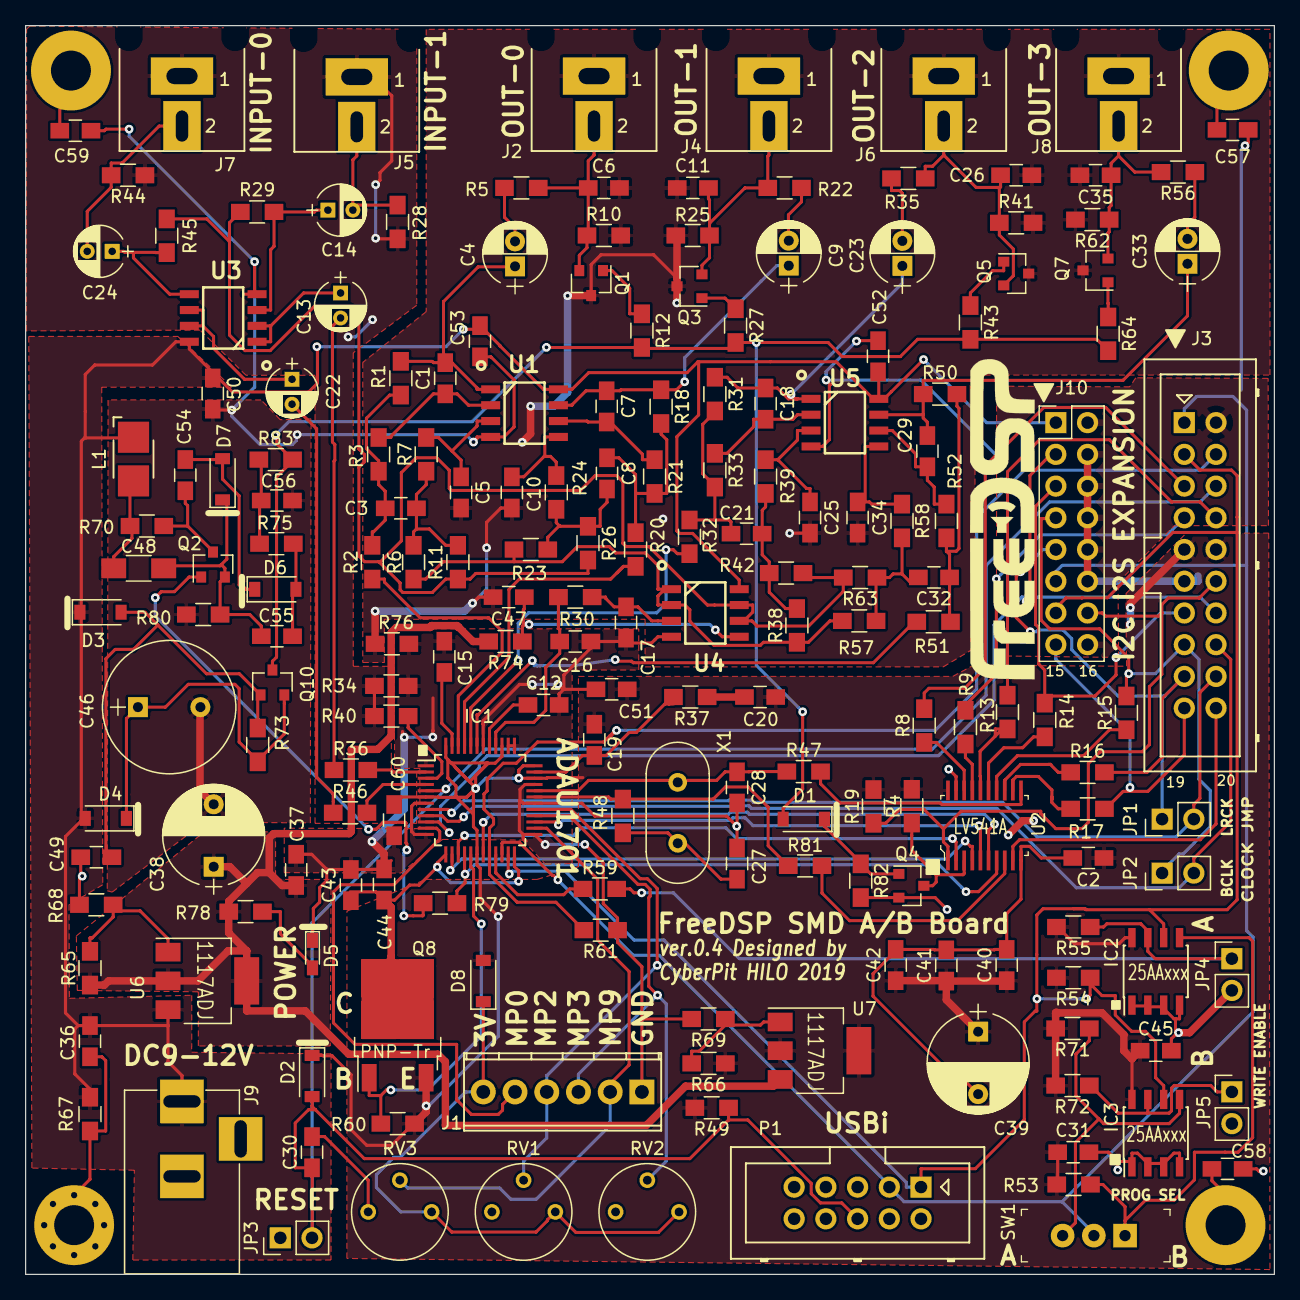
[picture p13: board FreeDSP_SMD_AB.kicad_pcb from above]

Board: 2 copper layers, 100.0 x 100.0 mm, 194 parts (0 on the bottom side), 125 nets.

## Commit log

2019-08-10 version 0.4 FreeDSP SMD A/B Board Top View
2019-08-10 Actual Audio performance (ADC -> DSP -> DAC)
